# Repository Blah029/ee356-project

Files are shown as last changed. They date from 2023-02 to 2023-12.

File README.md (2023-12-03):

# ee356-project
3rd year EE356: Electronic Product Design project

- Group 10
  - E/17/146: Jayawickrama JPD
  - E/17/234: Pandukabhaya VKM
  - E/17/371
- Timeline
  - Inital planning: 3rd-23rd Oct 2022
  - Project proposal: 17th-23rd Oct 2022
  - Design: 17th Oct - 13th Nov 2022
  - Simulation: 31st Oct - 13th Nov 2022
  - Prototyping: 7th-20th Nov 2022
  - Implementation: 21st Oct 2022 - 8th Jan 2022
  - Completion: 26th Dec 2022 - 15th Jan 2023
  - Product deployment: 16th-22nd Jan 2023
</br></br>
- altium_pcb  
  Altium project for the main circuit board
- arduino_main  
  Arduino code for the project
- fritzing_diagrams  
  Circuit diagrams of components done in Fritzing
- fusion_enclosure  
  3D model of the enclosure done in Fusion 360
- proteus_simulation  
  Simulation of the project done in Proteus

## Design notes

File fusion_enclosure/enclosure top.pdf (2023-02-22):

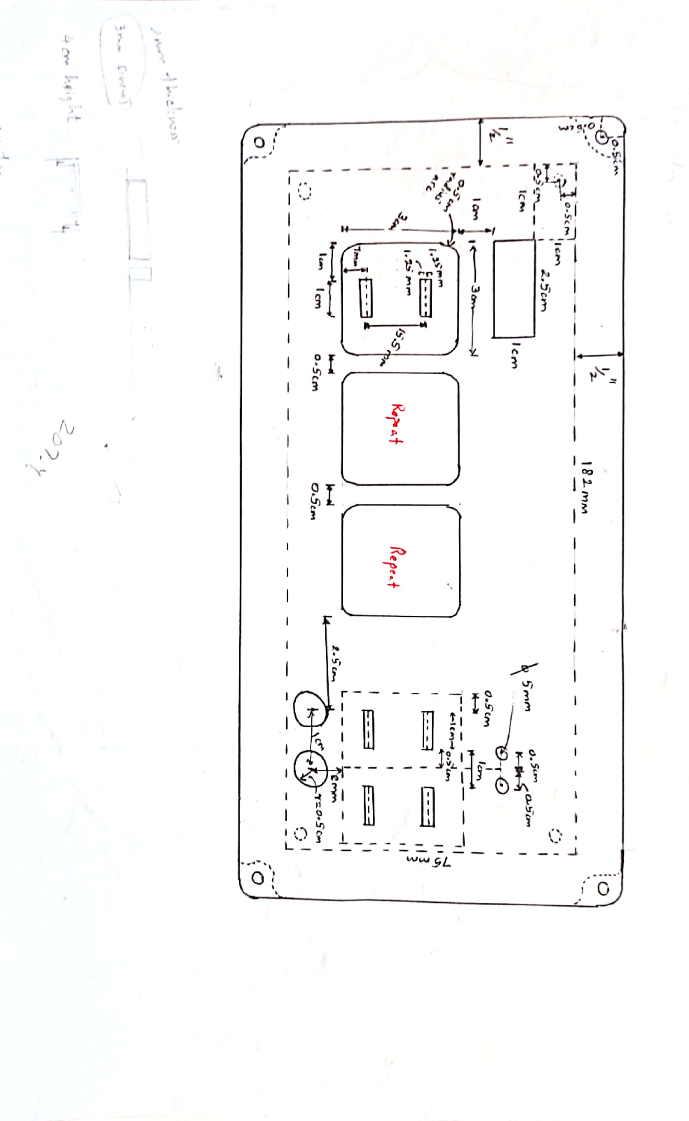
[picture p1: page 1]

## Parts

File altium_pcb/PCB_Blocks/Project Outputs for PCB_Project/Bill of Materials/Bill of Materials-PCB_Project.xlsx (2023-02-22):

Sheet: Part List Report
 | Component list |  |  | Bill of Materials for Project [PCB_Project.PrjPcb] (No PCB Document Selected)
 | Source Data From: | PCB_Project.PrjPcb |  |  | Contact: |  |  |  | Generated by:
 | Project: | PCB_Project.PrjPcb |  |  | <Parameter ClientCompanyName not found>
 | Variant: | None |  |  | <Parameter ClientContactName not found> |  |  |  | FEDEVEL
 |  |  |  |  | <Parameter ClientContactEmail not found>
 | Report Date: | 08 Feb 2023 | 1321h |  | <Parameter ClientWebsite not found> |  |  |  | http://www.fedevel.com
 | Print Date: | 2023-02-08 | 13:21:47
# | Category | Manufacturer 1 | Manufacturer Part Number 1 | Case/Package | Description | Quantity | Supplier 1 | Supplier Part Number 1 | Supplier Order Qty 1 | Supplier Stock 1 | Supplier Unit Price 1 | Supplier Subtotal 1 | Supplier Currency 1
1 | Uncategorized | Jameco Valuepro | KRS-1273B-R |  | Switch Push Button Tactile Off Momentary (On) Single Pole Single Throw Cap: 155389 155409 | 2 | Jameco | 155380 | 2000 | 2125 | 0.23 | 450.00 | USD
2 | Through-Hole Resistors | Yageo | CFR-25JB-52-220R | Axial | General Type Carbon Film Resistor 2.2kOhm 1/4W 5% Axial Bulk | 1 | Digi-Key | 220QBK-ND | 1000 | 0 | 0.01 | 11.44 | USD
3 | Through-Hole Resistors | Yageo | CFR-25JB-52-220R | Axial | General Type Carbon Film Resistor 3.3kOhm 1/4W 5% Axial Bulk, General Type Carbon Film Resistor 1kOhm 1/4W 5% Axial Bulk | 2 | Digi-Key | 220QBK-ND | 2000 | 0 | 0.01 | 22.88 | USD
4 | Through-Hole Resistors | Yageo | CFR-25JB-52-220R | Axial | General Type Carbon Film Resistor 220Ohm 1/4W 5% Axial Bulk | 16 | Digi-Key | 220QBK-ND | 16000 | 0 | 0.01 | 141.44 | USD
5 | Resistor Arrays | Bourns | 4309R-101-102LF | SIP | Res Thick Film NET 1K Ohm 2% 1.13W ±100ppm/°C BUS Molded 9-Pin SIP Pin Thru-Hole | 4 | Avnet | 32K9075 | 4000 | 21 | 1.42 | 5680.00 | USD
6 | LinearRegulator | ON Semiconductor / Fairchild | LM7805CT |  | Positive Voltage Regulator, 5 V, 1 A, -40 to 125 degC, 3-Pin TO-220, RoHS, Tube | 1 | Farnell | 1102157 | 1000 | 0 | 0.39 | 391.87 | USD
7 | LED Displays | Lumex | LDS-A5642RI | DIP | Single Digit Seven Segment Green 0.56" Common Anode Through Hole LED Display | 2 | Future Electronics | 8628562 | 2000 | 0 | 0.81 | 1610.00 | USD
8 | Diode | Lumex | SSA-LXB10HW-GF/LP |  | LED ARRAY 10X25MM 10SEG RED DIFF | 1 | Farnell | 1020492 | 1000 | 130 | 1.01 | 1008.17 | USD
9 | Diode | Broadcom Avago | HLMP-4700 |  | LED RED DIFFUSED T-1 3/4 T/H | 2 | Farnell | 1003232 | 2000 | 67296 | 0.26 | 524.11 | USD
10 | Crystals | TXC | 9B-16.000MBBK-B | Metal | Crystal 16MHz ±50ppm (Tol) ±50ppm (Stability) 20pF FUND 30Ohm 2-Pin DIP HC-49/S Thru-Hole Bulk | 1 | Arrow Electronics | 9B-16.000MBBK-B | 1000 | 908 | 0.14 | 139.70 | USD
11 | Connectors | Sullins | PPTC021LFBN-RC |  | Female, 2C, Straight, .100"CC; 3.20mm Tail, No Mt. 100u" Tin; PBT, Phos Bronze, 105 C | 1 | Digi-Key | S7000-ND | 1000 | 123778 | 0.15 | 152.78 | USD
12 |  |  |  |  |  | 3
13 |  |  |  |  |  | 4
14 |  | Microchip | ATMEGA328P-PU |  | 8-bit AVR Microcontroller, 32KB Flash, 1KB EEPROM, 2KB SRAM, 28-pin PDIP, Industrial Grade (-40°C to 85°C) | 1 | Rs | 1310276 | 1000 | 0 | 2.75 | 2753.98 | USD
15 |  | Texas Instruments | SN74HC595N |  | 8-Bit Shift Registers With 3-State Output Registers, N0016A, TUBE | 1 | Rs | 1000763 | 1000 | 3750 | 0.46 | 456.17 | USD
16 |  | Texas Instruments | SN74LS47N |  | BCD-to-7-Segment Decoder / Driver, 4.75 to 5.25 V, 0 to 70 degC, 16-pin DIP (N16), Pb-Free (RoHS) | 2 | Digi-Key | 296-3712-5-ND | 2000 | 5948 | 0.82 | 1641.52 | USD
17 |  | Murata | RCER71E106K3A2H03B | Radial | Cap Ceramic 10uF 25V X7R ±10% Radial 2.5mm +125°C Automotive Bulk | 2 | Future Electronics | 2087210 | 2000 | 0 | 0.36 | 720.00 | USD
18 |  | KEMET | C315C220K1G5TA |  | Capacitor, Ceramic, 22 pF, +/-10 %, 100 V, -55 to 125 degC, 2-Pin THD, RoHS, Bulk | 3 | Farnell | 2938971 | 3000 | 0 | 0.14 | 425.84 | USD
19 |  | TI National Semiconductor | LM3914N-1 | DIP | IC DRVR DOT/BAR DISPLAY 18DIP | 1 |  |  |  | 0
20 |  | Texas Instruments | SN74LS165AN |  | Serial-out shift registers, N0016A, TUBE | 3 | Newark | 28AH5081 | 3000 | 0 | 0.69 | 2058.00 | USD
 |  |  |  |  |  | 53 |  |  | 45000 |  |  | 18187.9
Approved |  |  |  | Notes
 |  |  |  |  |  | 1000 | pcs: | Total |  | 18187.9 |  | USD
 |  |  |  |  |  |  |  | Price for 1pcs |  | 18.19 |  | USD

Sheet: Project Information
Project Full Path | D:\continuum\eng\elec\y3s2\ee356\projects\ee356-project\ee356-project\altium_pcb\PCB_Project\PCB_Project.PrjPcb
Project Filename | PCB_Project.PrjPcb
Variant Name | None
Data-Source Filename | PCB_Project.PrjPcb
Data-Source Full Path | D:\continuum\eng\elec\y3s2\ee356\projects\ee356-project\ee356-project\altium_pcb\PCB_Project\PCB_Project.PrjPcb
Title | Bill of Materials for Project [PCB_Project.PrjPcb] (No PCB Document Selected)
Total Quantity | 53
Report Time | 1321h
Report Date | 08 Feb 2023
Report Date & Tine | 08 Feb 2023 1321h
Output Name | Bill of Materials
Output Type | BomReport
Output Generator Name | BOM
Output Generator Description | Bill of Materials

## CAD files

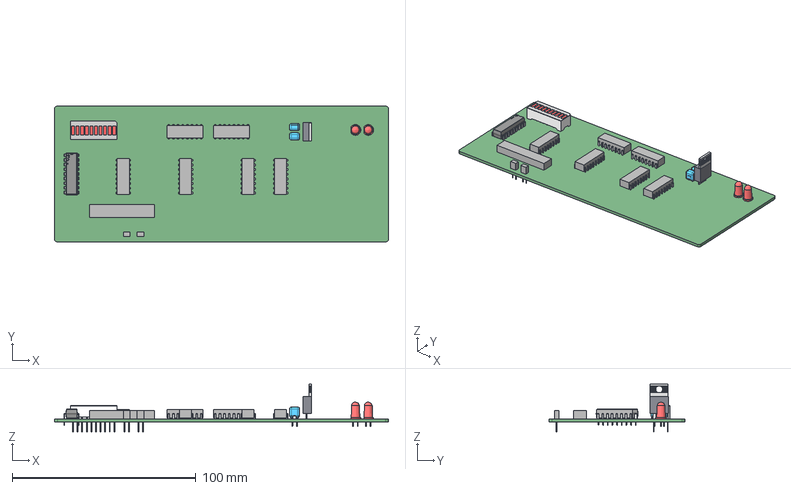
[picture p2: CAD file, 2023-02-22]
altium_pcb/PCB_Blocks/Project Outputs for Free Documents/Export STEP/PCB1.step
182.0 x 74.0 x 25.9 mm
Extruded x 342
Logo x 2
Leads x 2
MainBody x 2
Texas Logo Yury - Copy
Texas Logo Yury
top
led
pins x 3
led base x 2
led head x 2

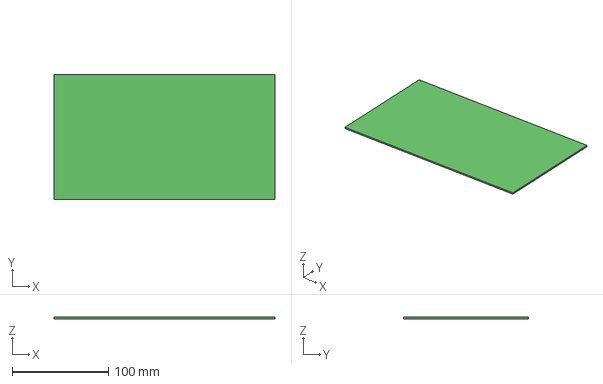
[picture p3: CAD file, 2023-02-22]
altium_pcb/PCB_Blocks/Project Outputs for PCB_Blocks/Export STEP/PCB_Blocks.step
230.0 x 130.0 x 1.69 mm

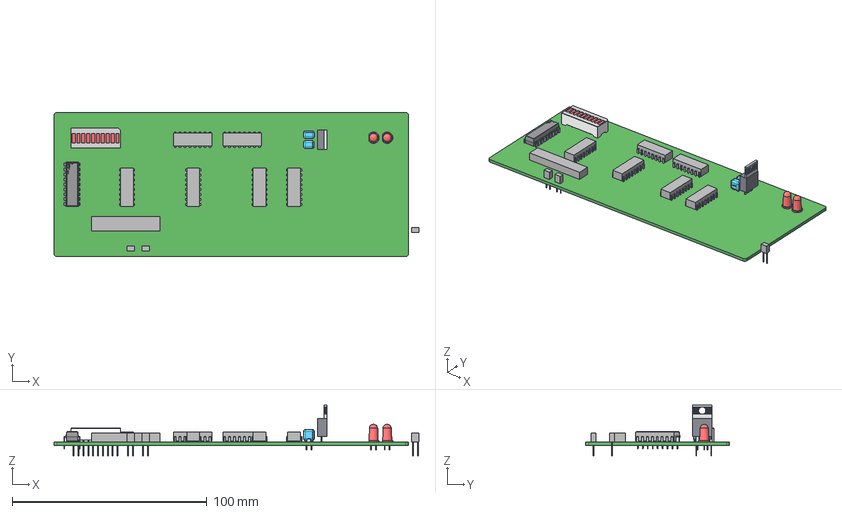
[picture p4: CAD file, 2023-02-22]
altium_pcb/PCB_Blocks/Project Outputs for PCB_Project/Export STEP/PCB1.step
187.3 x 74.0 x 25.9 mm
Extruded x 345
Logo x 2
Leads x 2
MainBody x 2
Texas Logo Yury - Copy
Texas Logo Yury
top
led
pins x 3
led base x 2
led head x 2

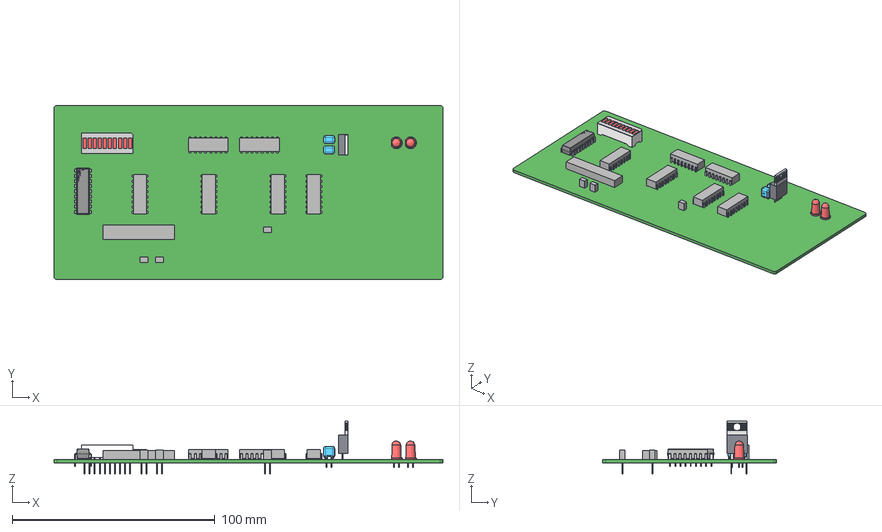
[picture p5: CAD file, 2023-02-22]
altium_pcb/PCB_Project/Project Outputs for PCB_Project/Export STEP/PCB1.step
192.0 x 86.0 x 25.9 mm
Extruded x 345
Logo x 2
Leads x 2
MainBody x 2
Texas Logo Yury - Copy
Texas Logo Yury
top
led
pins x 3
led base x 2
led head x 2

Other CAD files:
fusion_enclosure/Top of the Enclosure v13.dwg
fusion_enclosure/Top of the Enclosure v13.f3z

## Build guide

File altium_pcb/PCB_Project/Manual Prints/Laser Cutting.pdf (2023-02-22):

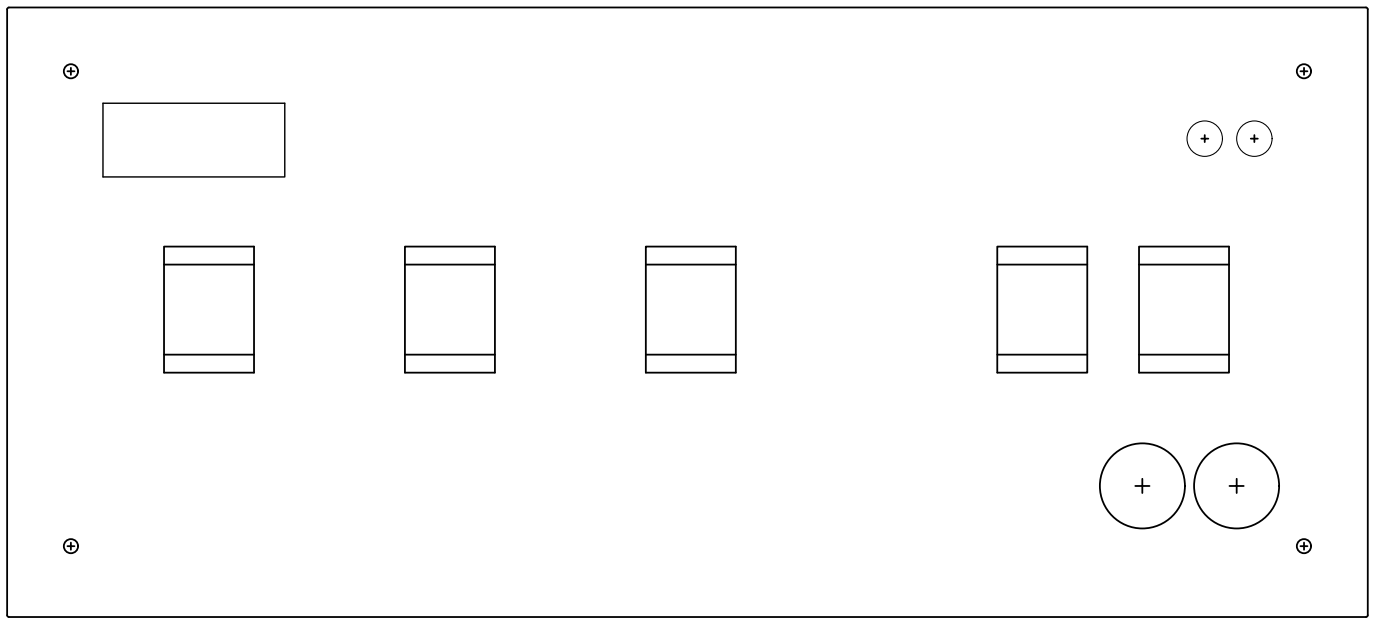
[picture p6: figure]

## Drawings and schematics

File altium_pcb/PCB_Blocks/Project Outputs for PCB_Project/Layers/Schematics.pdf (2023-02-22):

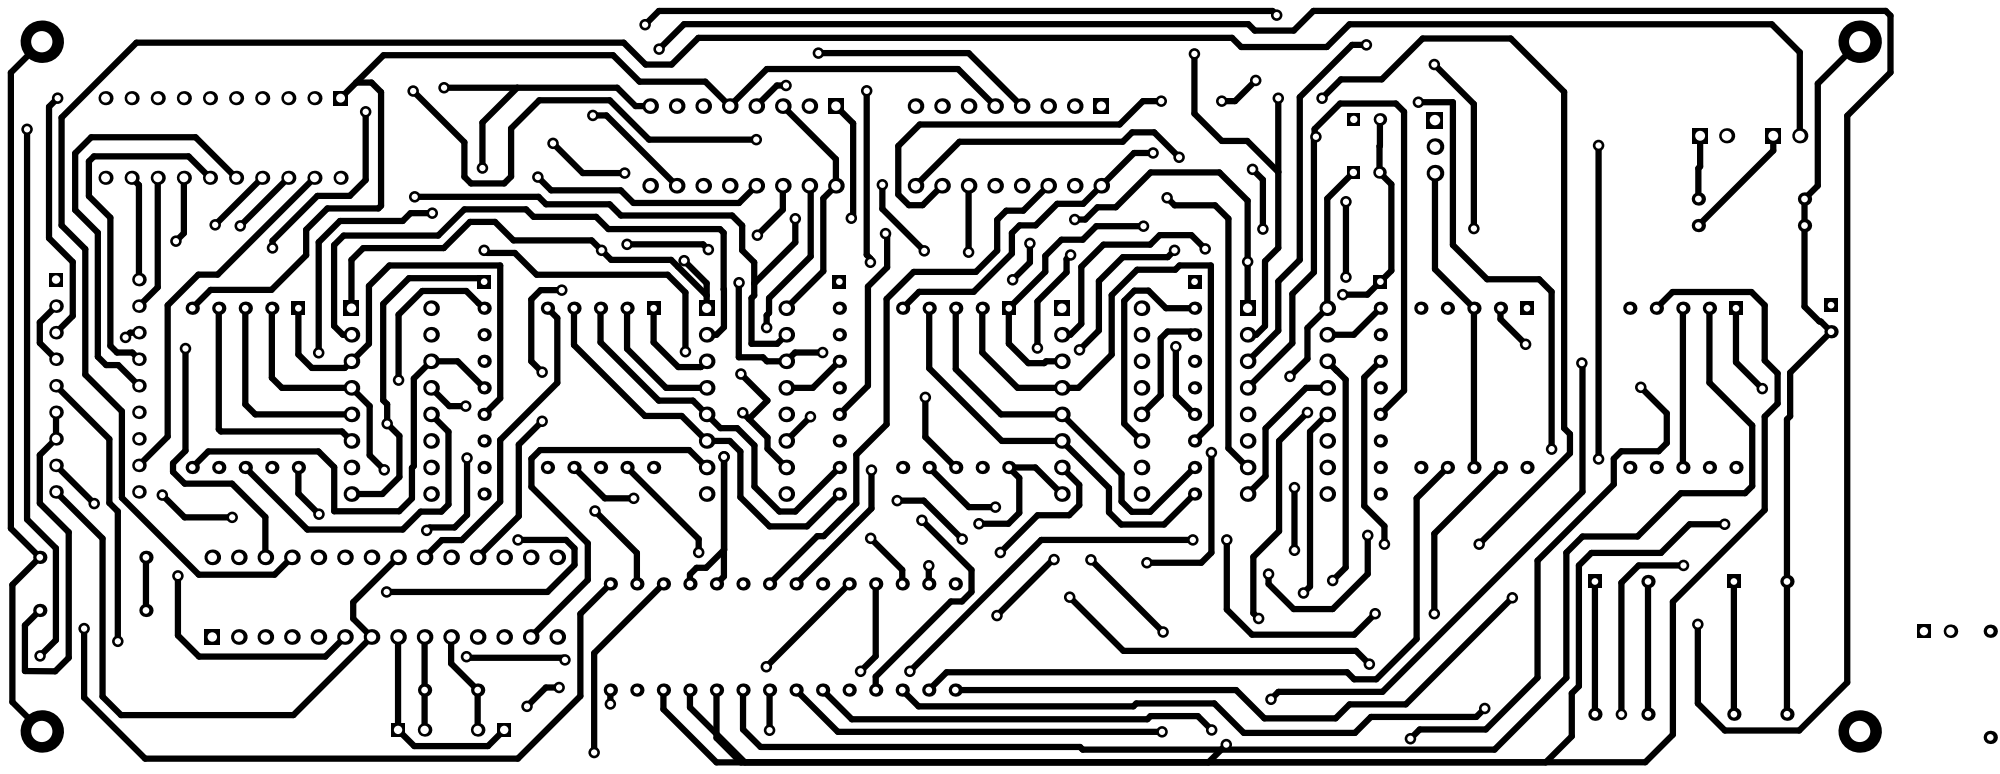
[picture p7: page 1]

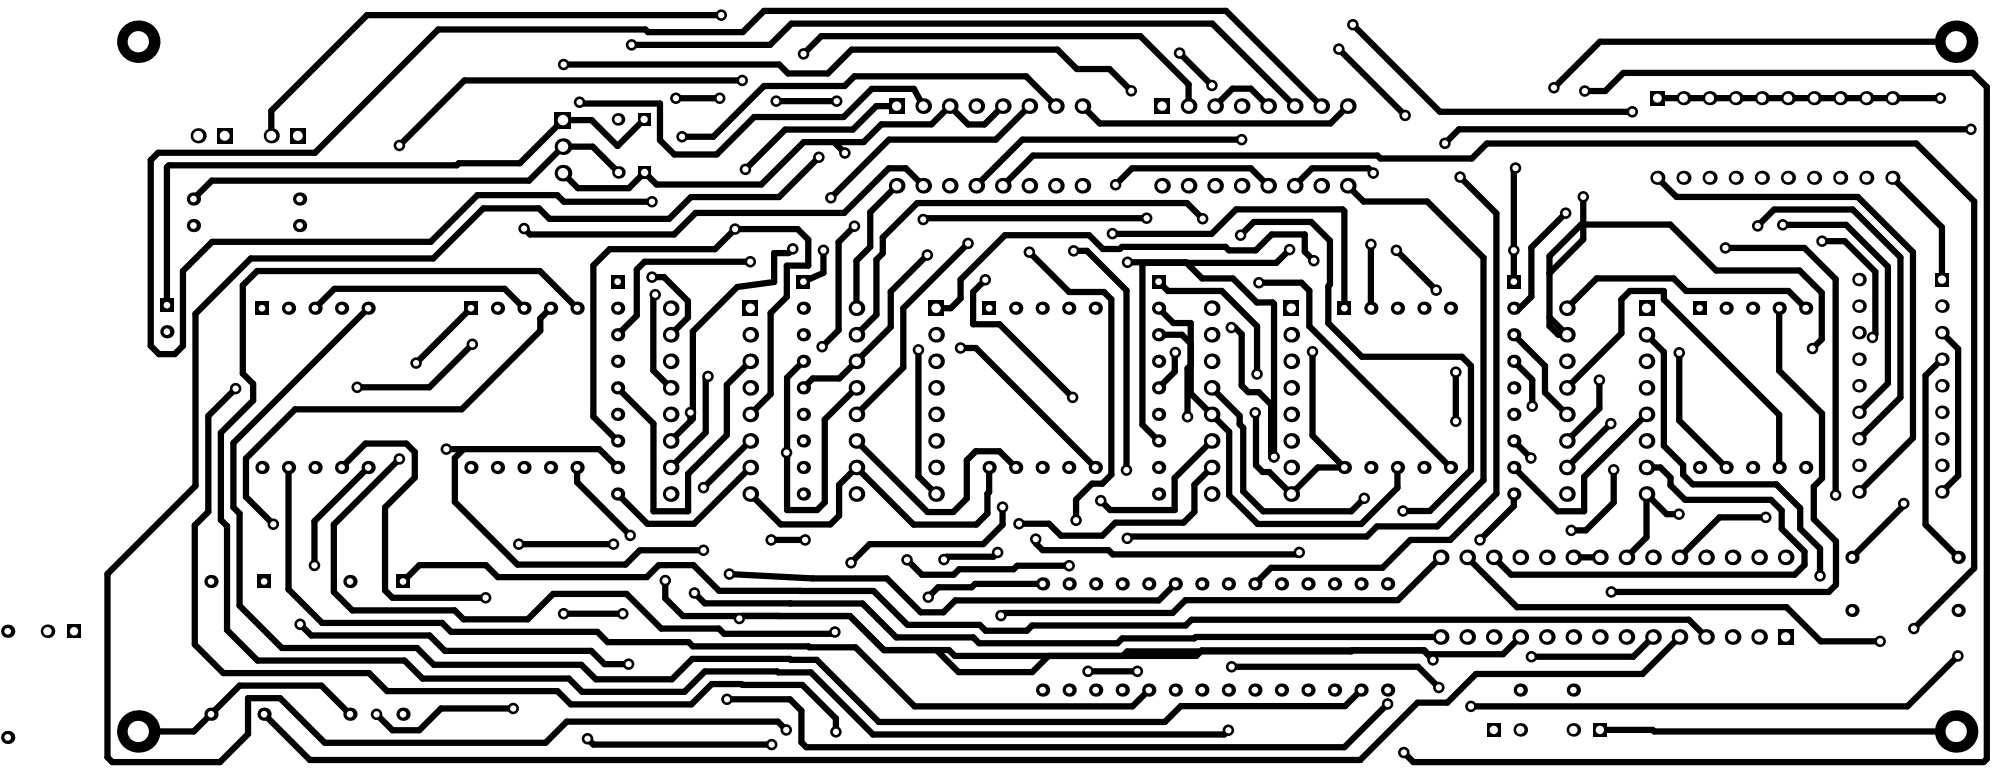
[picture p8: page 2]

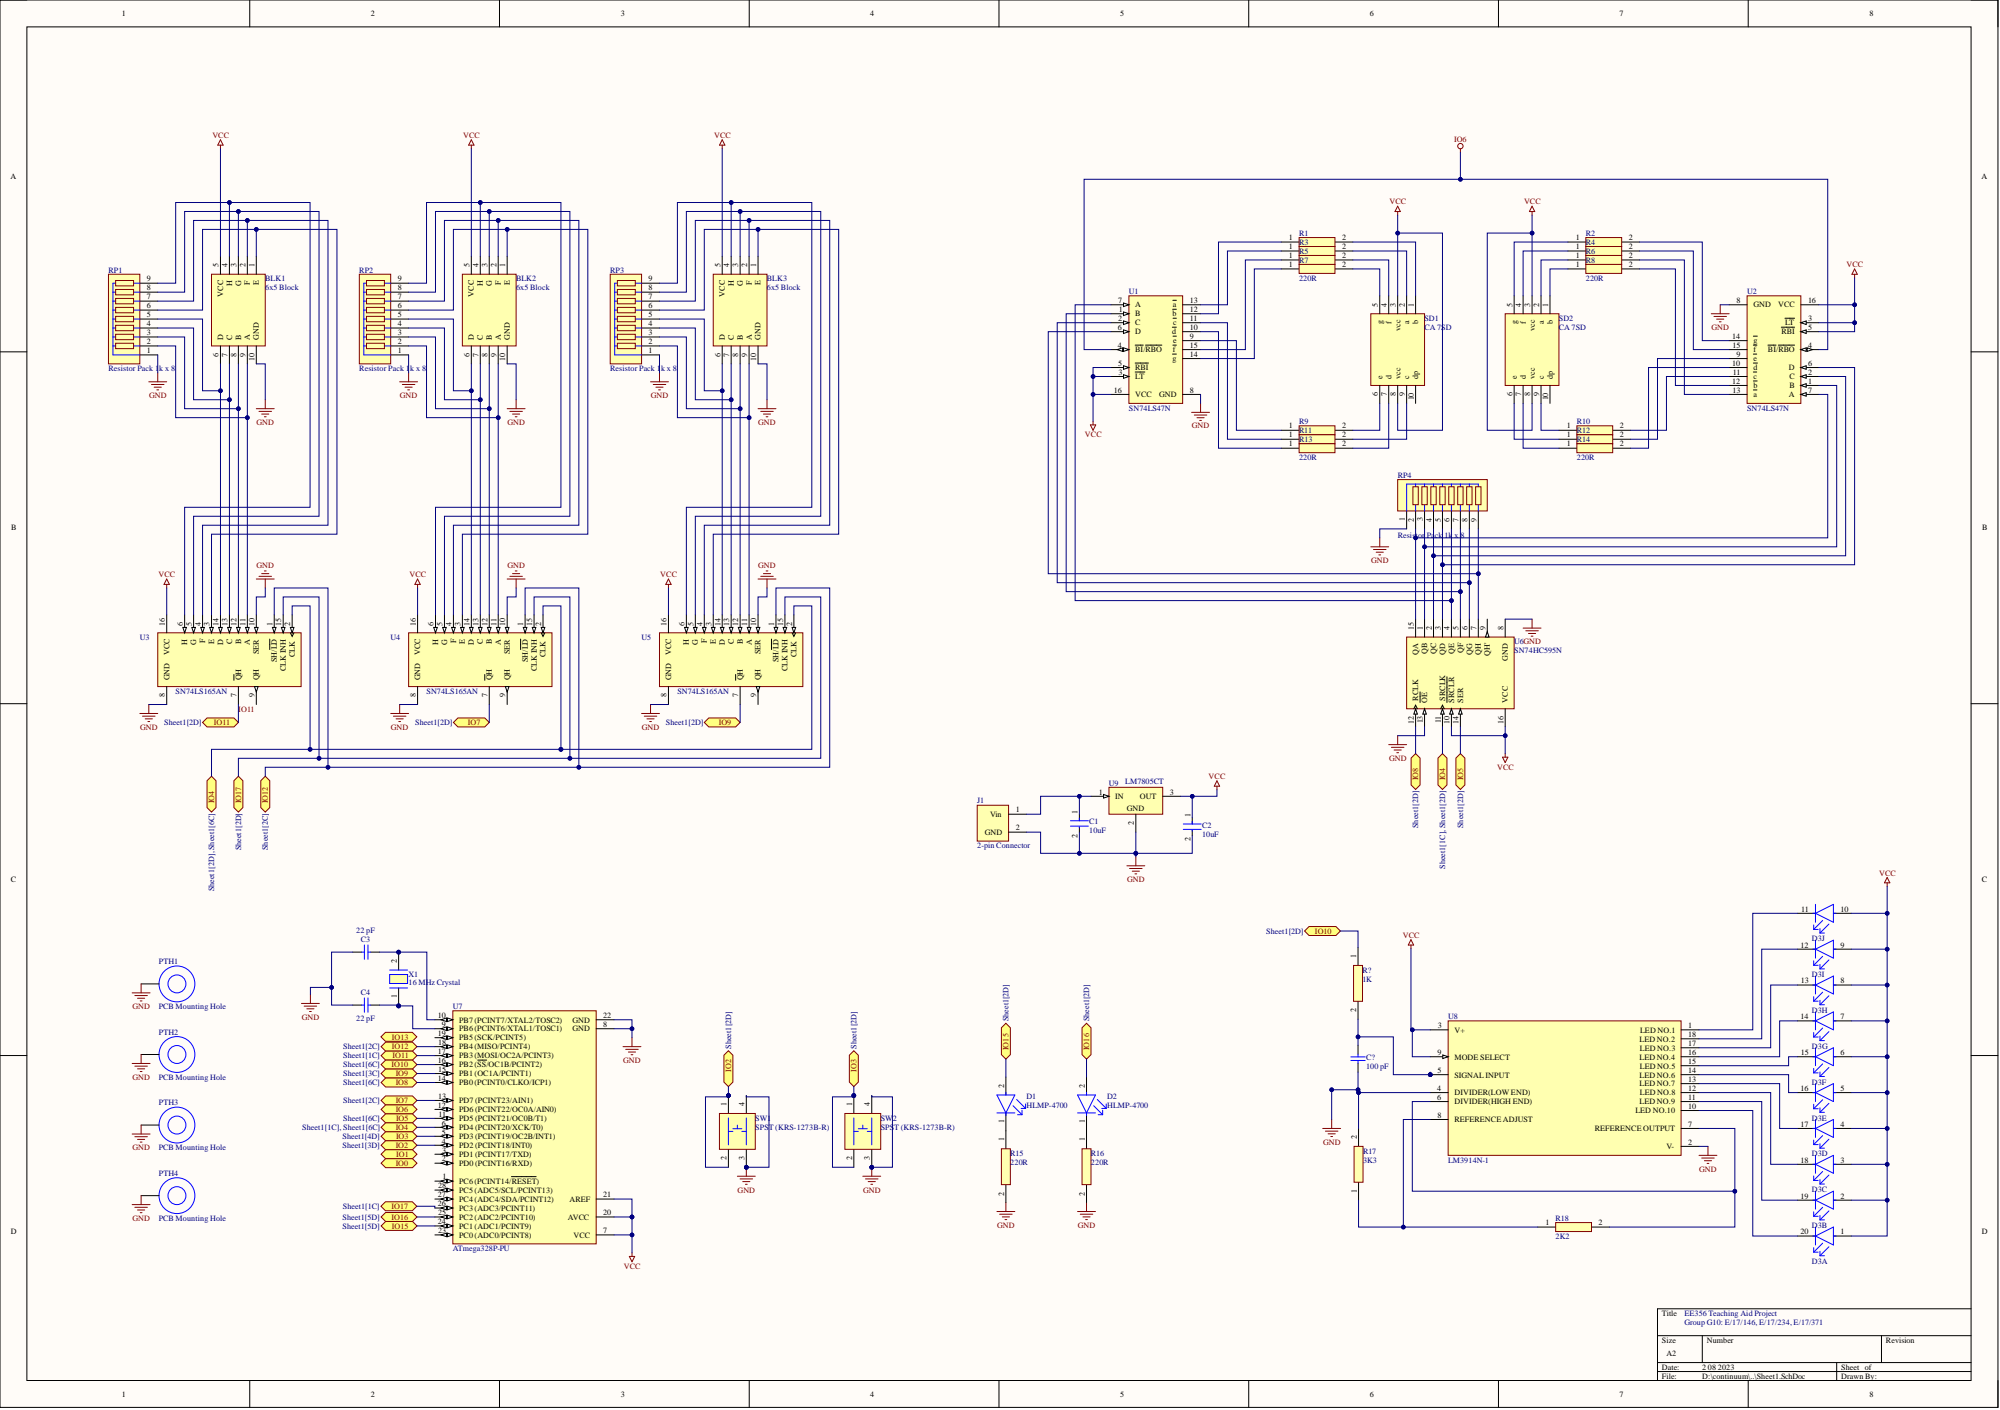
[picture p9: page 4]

GND PCB Mounting Hole

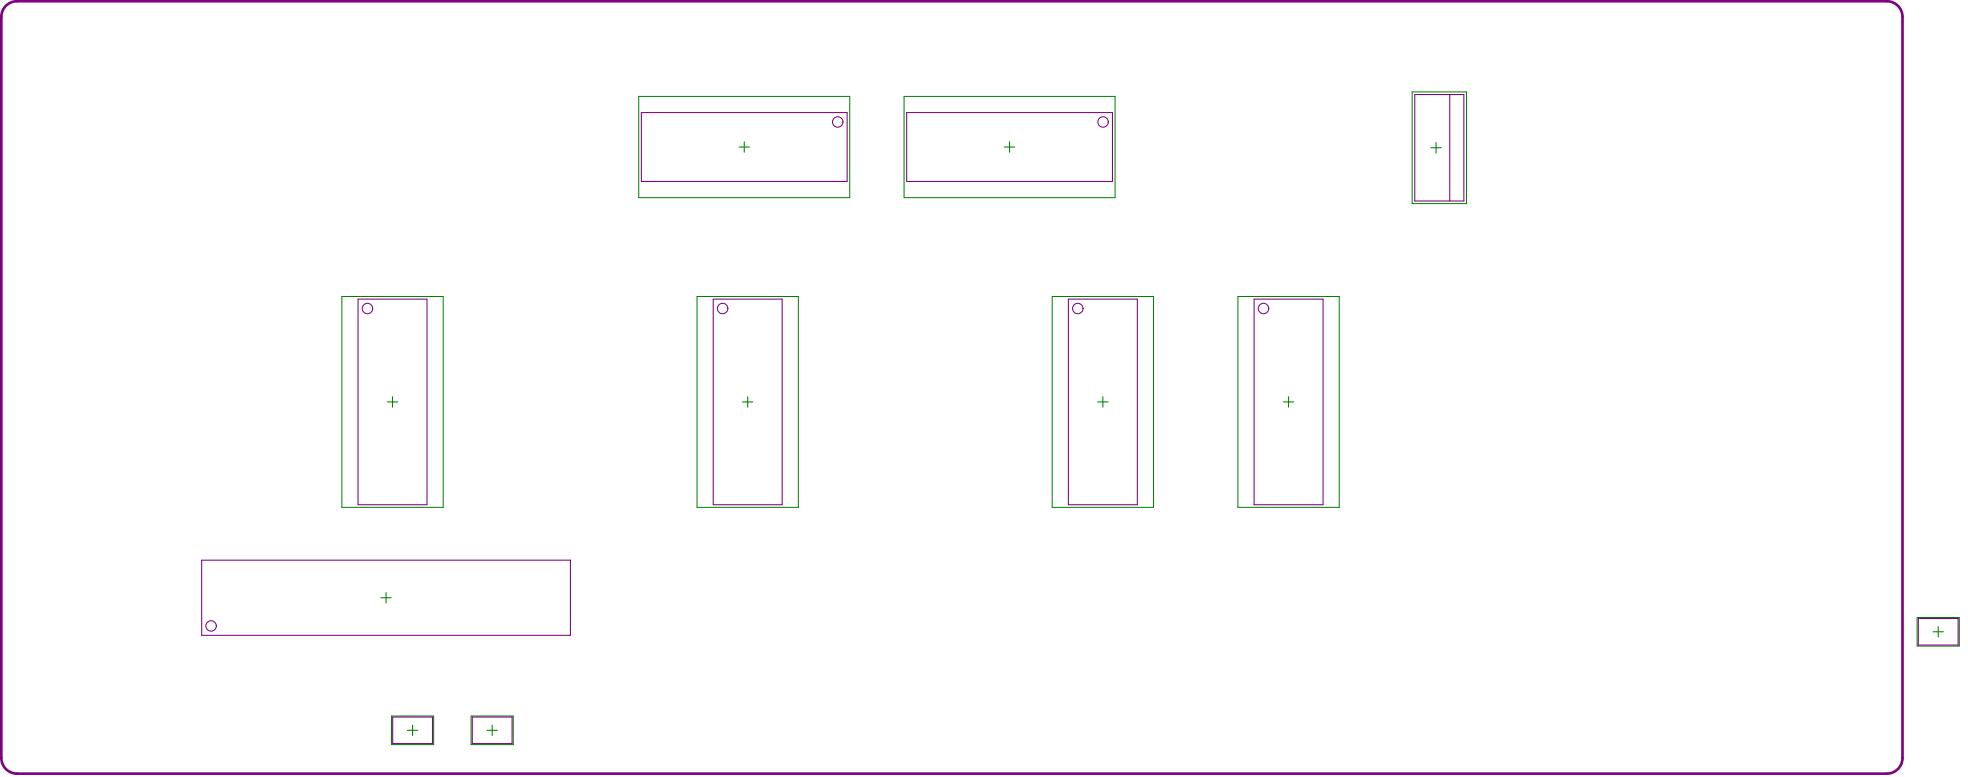
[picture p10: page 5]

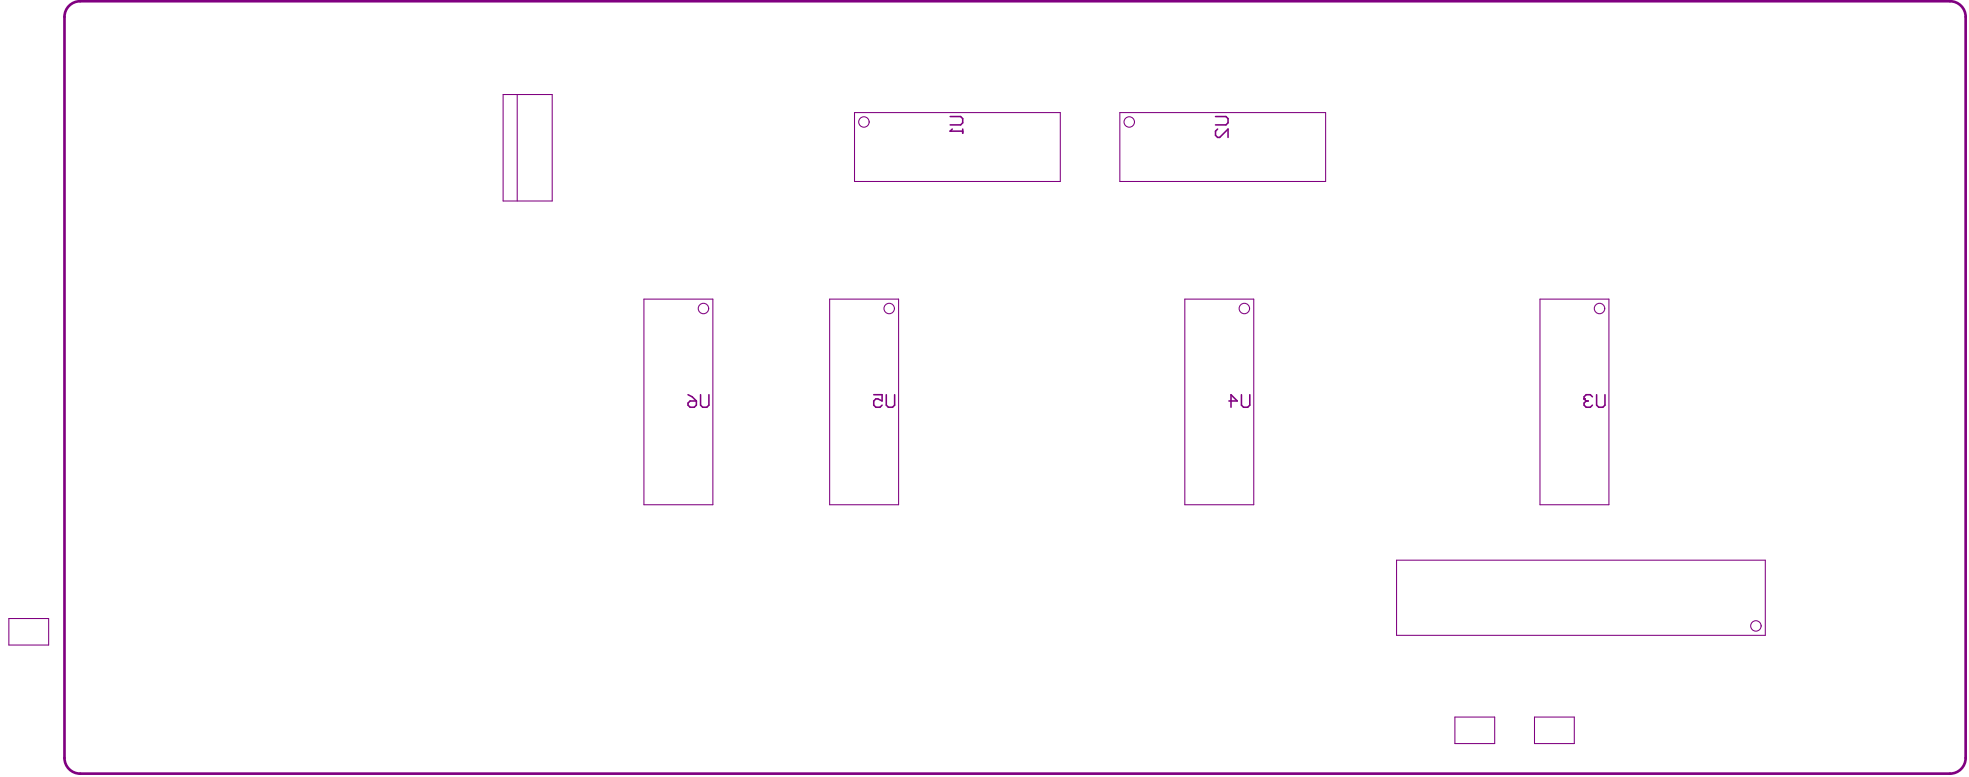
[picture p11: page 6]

Component | list | | Bill of Materials for Project [PCB_Project.PrjPcb] (No PCB Document Selected)
Source Data From: PCB_Project.PrjPcb | | Contact: | | Generated by:
Project: PCB_Project.PrjPcb | <Parameter ClientCompanyName not found>
Variant: | None | <Parameter ClientContactName not found> | FEDEVEL <Parameter ClientContactEmail not found>
Report Date: | 08 Feb 2023 | 1319h | <Parameter ClientWebsite not found> | http://www.fedevel.com

### Print Date: 08-Feb-23 1:20:32 PM

# | Category | Manufacturer 1 | Manufacturer Part Number 1 | Case/Package | Description | Quantity | Supplier 1 | Supplier Part Number 1 | Supplier Order Qty 1 | Supplier Stock 1 | Supplier Unit Price 1 | Supplier Subtotal 1 | Supplier Currency 1

1 | Uncategorized | Jameco Valuepro | KRS-1273B-R | | Sw itch Push Button Tactile Off Momentary | 2 | Jameco | 155380 | 2000 | 2125 | 0.23 | 450.00 | USD
2 | Through-Hole Resistors | Yageo | CFR-25JB-52-220R | Axial | General Type Carbon Film Resistor 2.2kOhm | 1 | Digi-Key | 220QBK-ND | 1000 | 0 | 0.01 | 11.44 | USD
3 | Through-Hole Resistors | Yageo | CFR-25JB-52-220R | Axial | General Type Carbon Film Resistor 3.3kOhm | 2 | Digi-Key | 220QBK-ND | 2000 | 0 | 0.01 | 22.88 | USD
4 | Through-Hole Resistors | Yageo | CFR-25JB-52-220R | Axial | General Type Carbon Film Resistor 220Ohm | 16 | Digi-Key | 220QBK-ND | 16000 | 0 | 0.01 | 141.44 | USD
5 | Resistor Arrays | Bourns | 4309R-101-102LF | SIP | Res Thick Film NET 1K Ohm 2% 1.13W | 4 | Avnet | 32K9075 | 4000 | 21 | 1.42 | 5680.00 | USD
6 | LinearRegulator | ON Semiconductor / Fairchild | LM7805CT | | Positive Voltage Regulator, 5 V, 1 A, -40 to | 1 | Farnell | 1102157 | 1000 | 0 | 0.39 | 391.87 | USD
7 | LED Displays | Lumex | LDS-A5642RI | DIP | Single Digit Seven Segment Green 0.56" | 2 | Future Electronics | 8628562 | 2000 | 0 | 0.81 | 1610.00 | USD
8 | Diode | Lumex | SSA-LXB10HW-GF/LP | | LED ARRAY 10X25MM 10SEG RED DIFF | 1 | Farnell | 1020492 | 1000 | 130 | 1.01 | 1008.17 | USD
9 | Diode | Broadcom Avago | HLMP-4700 | | LED RED DIFFUSED T-1 3/4 T/H | 2 | Farnell | 1003232 | 2000 | 67296 | 0.26 | 524.11 | USD
10 | Crystals | TXC | 9B-16.000MBBK-B | Metal | Crystal 16MHz ±50ppm (Tol) ±50ppm | 1 | Arrow Electronics | 9B-16.000MBBK-B | 1000 | 908 | 0.14 | 139.70 | USD
11 | Connectors | Sullins | PPTC021LFBN-RC | | Female, 2C, Straight, .100"CC; 3.20mm Tail, | 1 | Digi-Key | S7000-ND | 1000 | 123778 | 0.15 | 152.78 | USD
12 | | | | | | 3
13 | | | | | | 4
14 | | Microchip | ATMEGA328P-PU | | 8-bit AVR Microcontroller, 32KB Flash, 1KB | 1 | Rs | 1310276 | 1000 | 0 | 2.75 | 2753.98 | USD
15 | | Texas Instruments | SN74HC595N | | 8-Bit Shift Registers With 3-State Output | 1 | Rs | 1000763 | 1000 | 3750 | 0.46 | 456.17 | USD
16 | | Texas Instruments | SN74LS47N | | BCD-to-7-Segment Decoder / Driver, 4.75 to | 2 | Digi-Key | 296-3712-5-ND | 2000 | 5948 | 0.82 | 1641.52 | USD
17 | | Murata | RCER71E106K3A2H03B | Radial | Cap Ceramic 10uF 25V X7R ±10% Radial | 2 | Future Electronics | 2087210 | 2000 | 0 | 0.36 | 720.00 | USD
18 | | KEMET | C315C220K1G5TA | | Capacitor, Ceramic, 22 pF, +/-10 %, 100 V, - | 3 | Farnell | 2938971 | 3000 | 0 | 0.14 | 425.84 | USD
19 | | TI National Semiconductor | LM3914N-1 | DIP | IC DRVR DOT/BAR DISPLAY 18DIP | 1 | | | | 0
20 | | Texas Instruments | SN74LS165AN | | Serial-out shift registers, N0016A, TUBE | 3 | New ark | 28AH5081 | 3000 | 0 | 0.69 | 2058.00 | USD
| | | | | | 53 | | | 45000 | 18187.9
Approved | | | | Notes Price for 1pcs | | | | | | | | USD
1000 pcs: | Total | USD

18187.9

18.19

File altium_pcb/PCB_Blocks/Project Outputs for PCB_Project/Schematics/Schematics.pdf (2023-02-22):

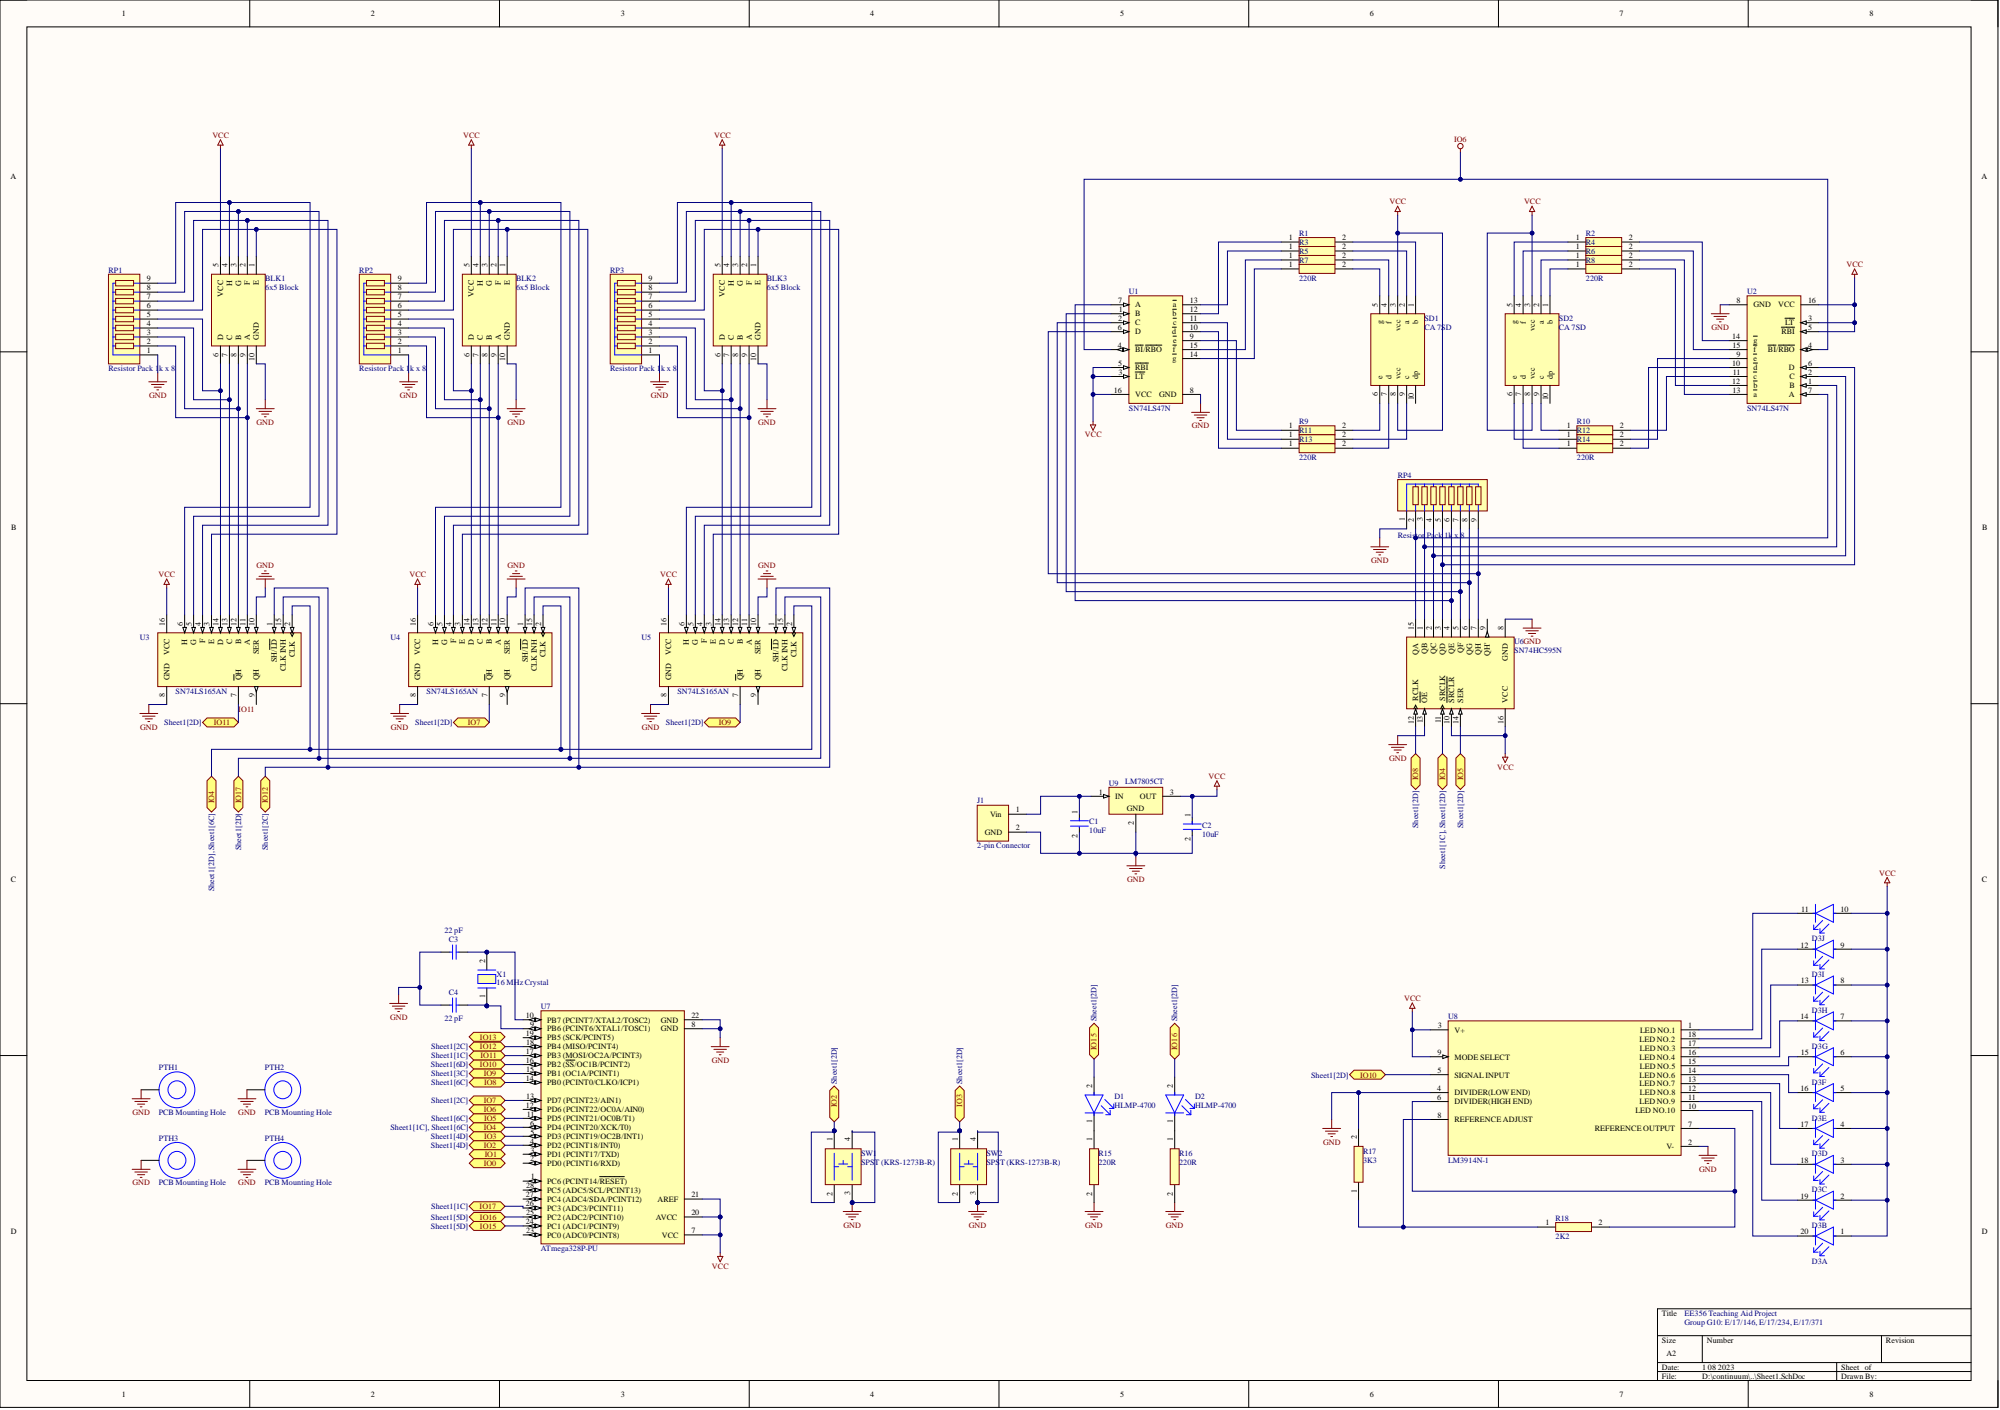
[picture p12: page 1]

GND PCB Mounting Hole

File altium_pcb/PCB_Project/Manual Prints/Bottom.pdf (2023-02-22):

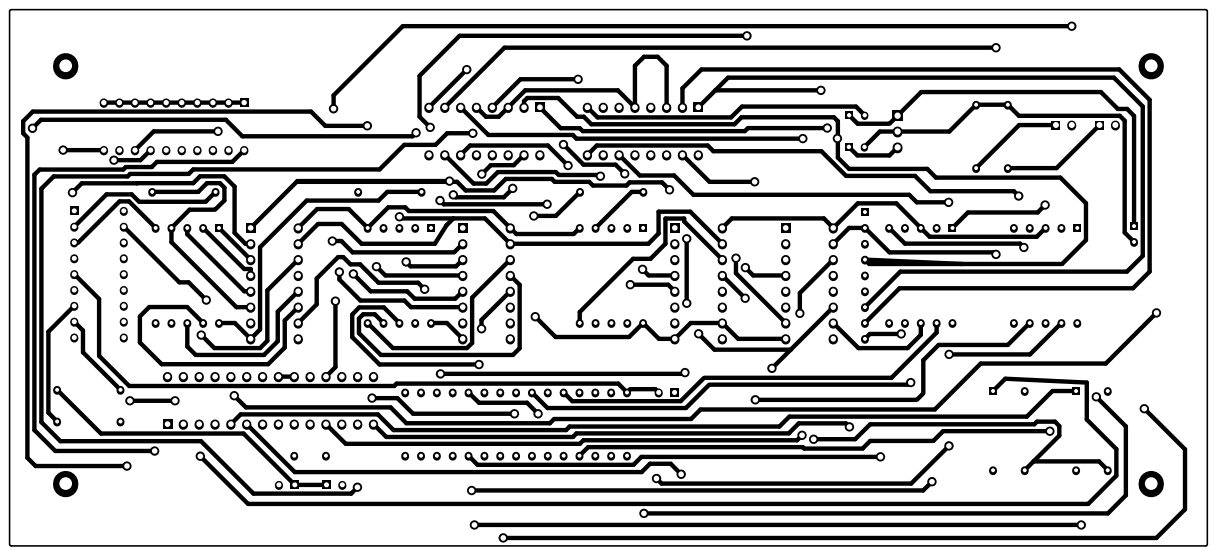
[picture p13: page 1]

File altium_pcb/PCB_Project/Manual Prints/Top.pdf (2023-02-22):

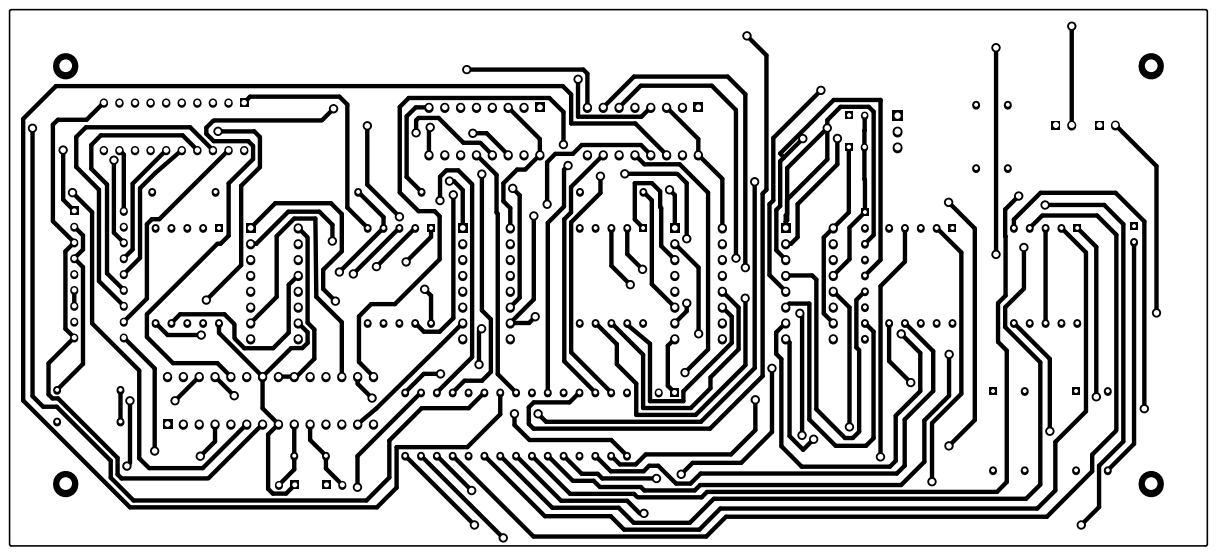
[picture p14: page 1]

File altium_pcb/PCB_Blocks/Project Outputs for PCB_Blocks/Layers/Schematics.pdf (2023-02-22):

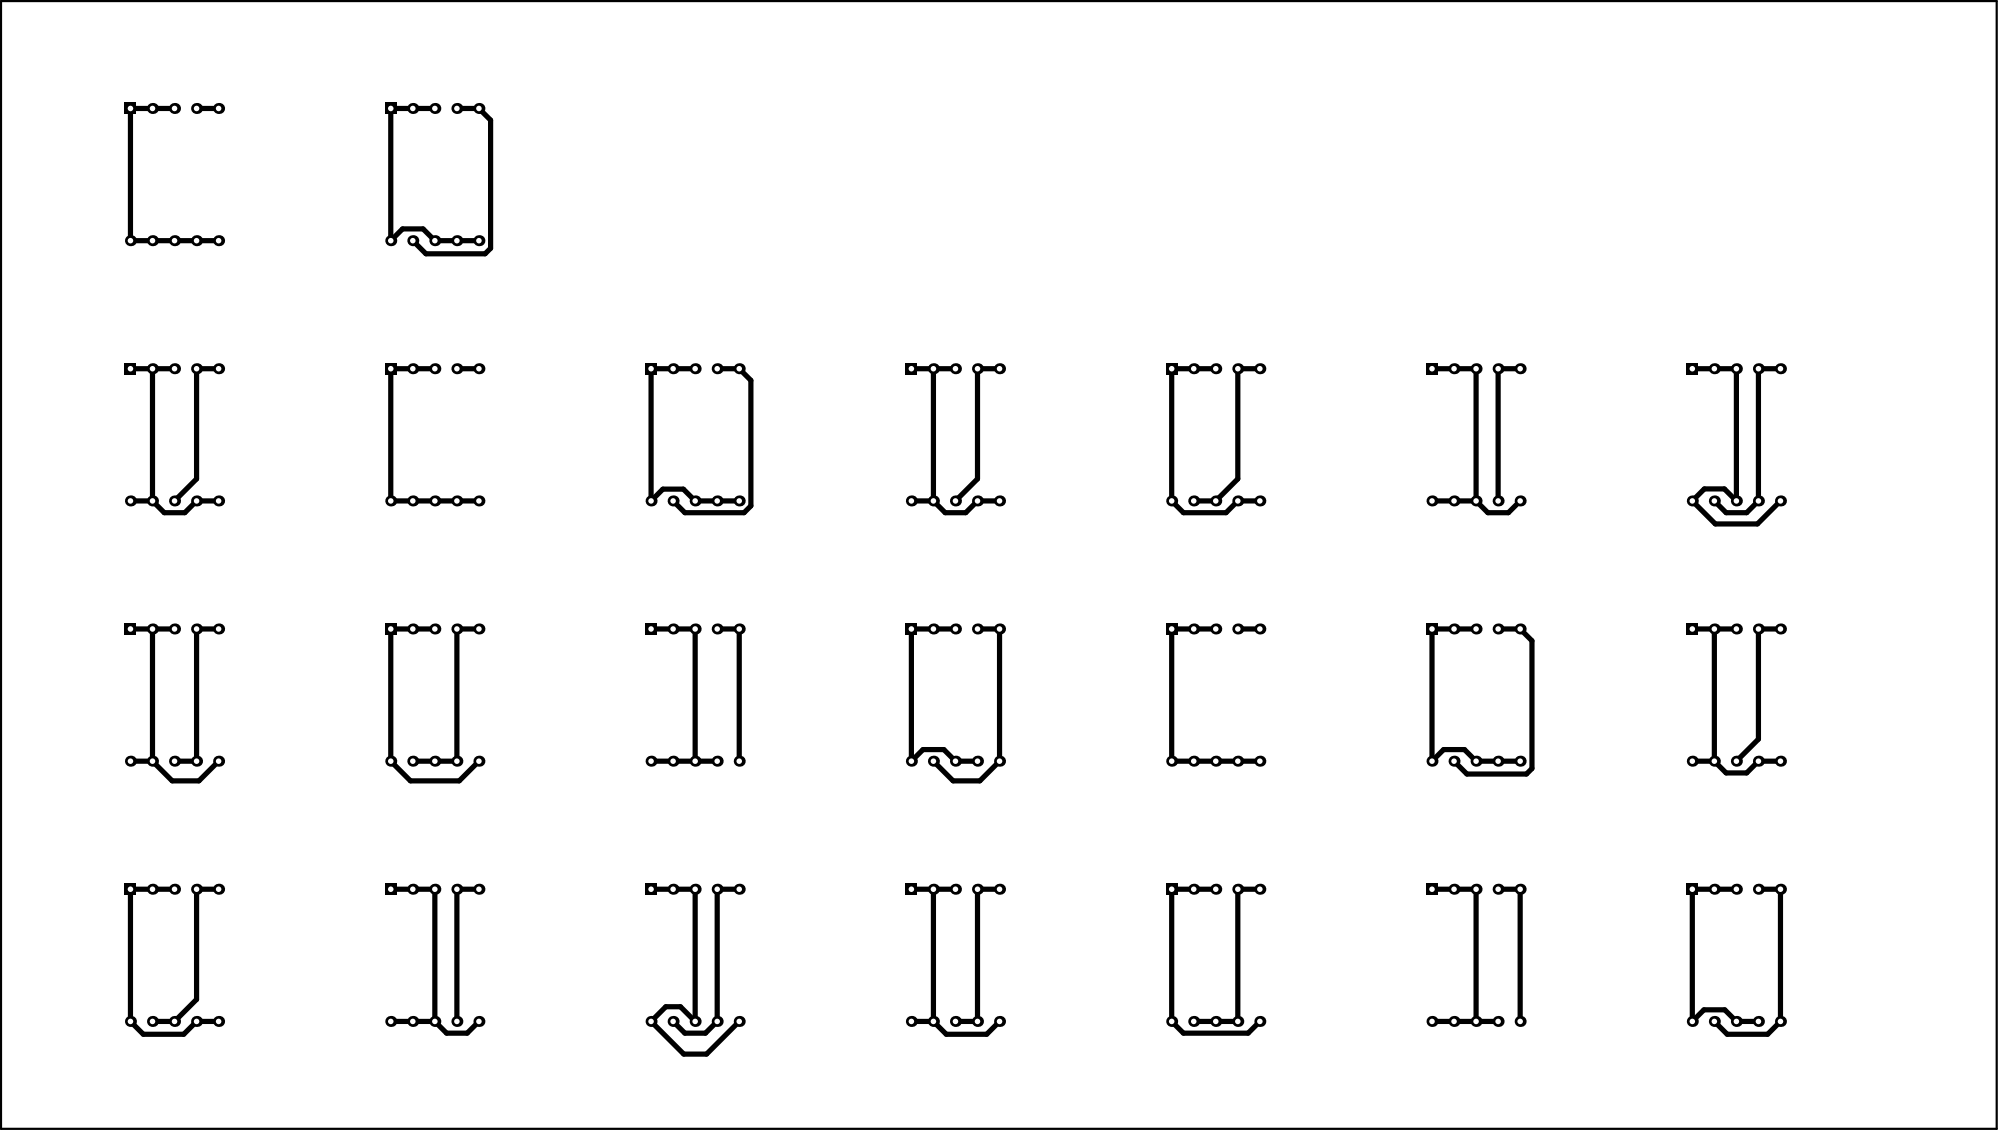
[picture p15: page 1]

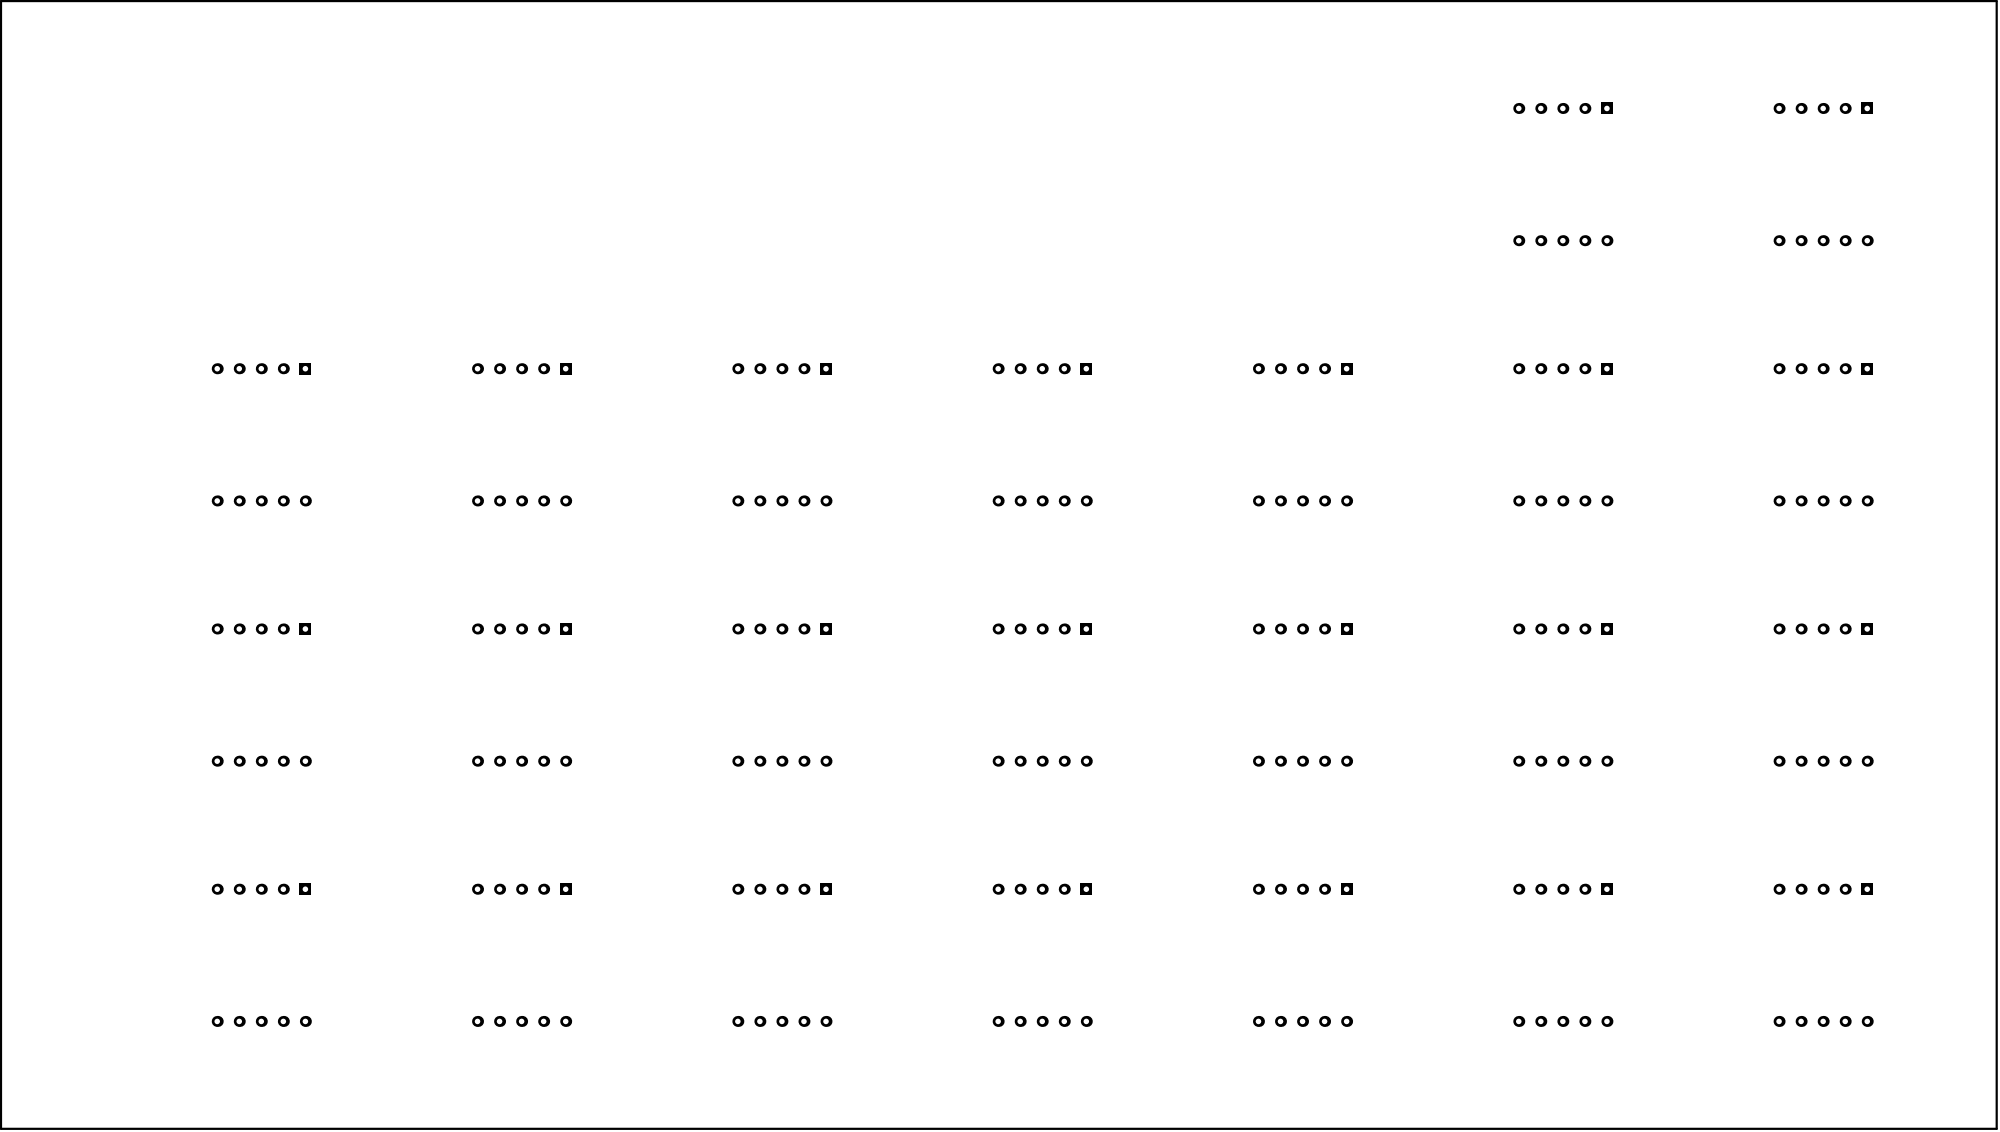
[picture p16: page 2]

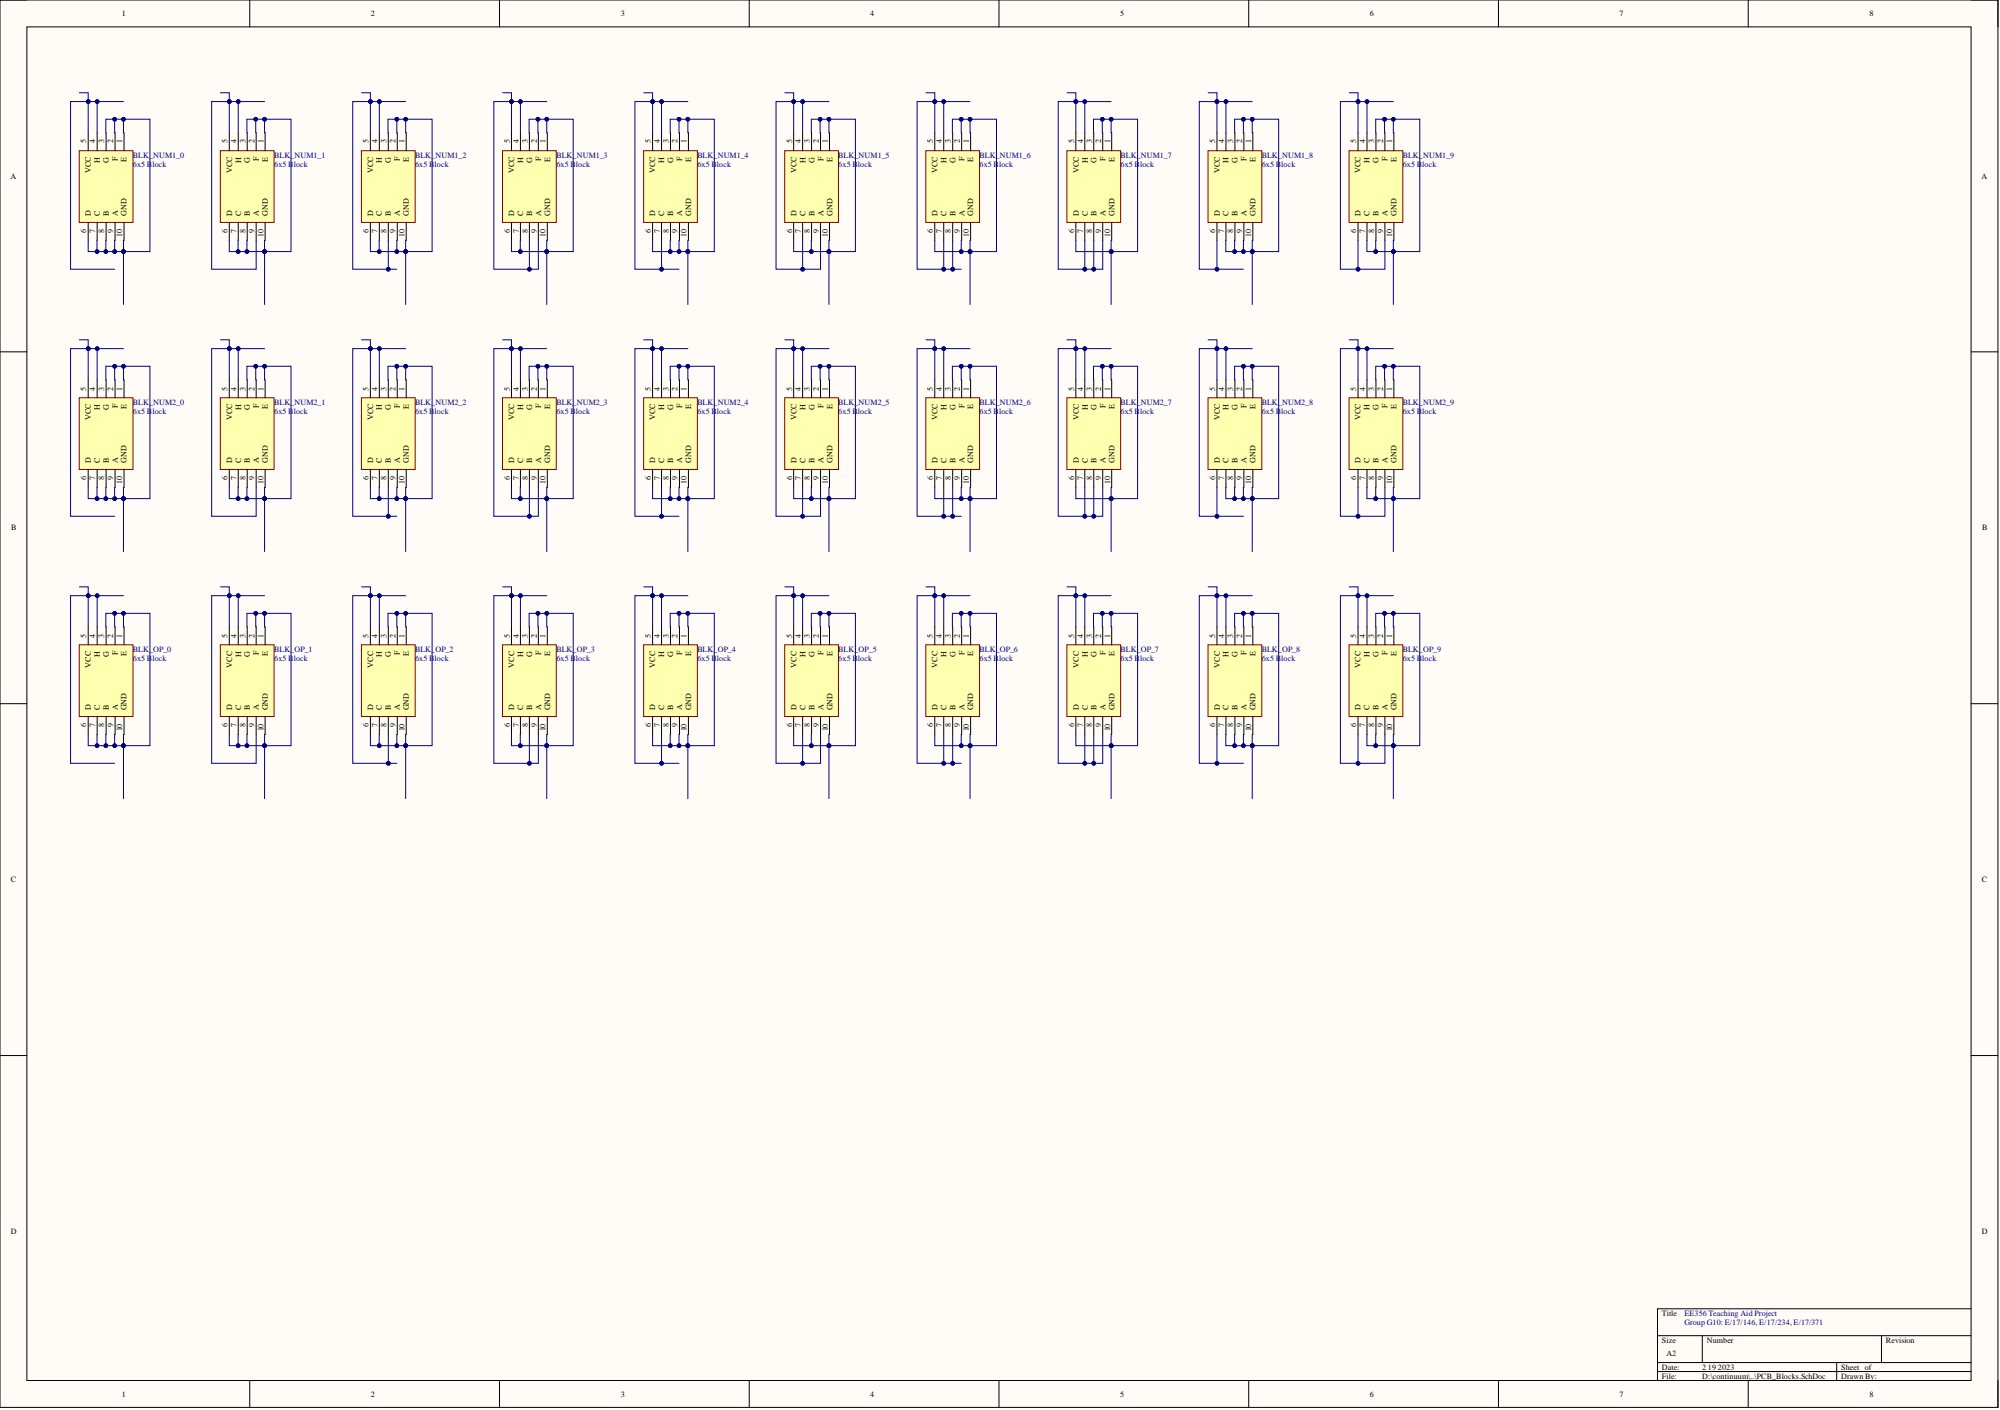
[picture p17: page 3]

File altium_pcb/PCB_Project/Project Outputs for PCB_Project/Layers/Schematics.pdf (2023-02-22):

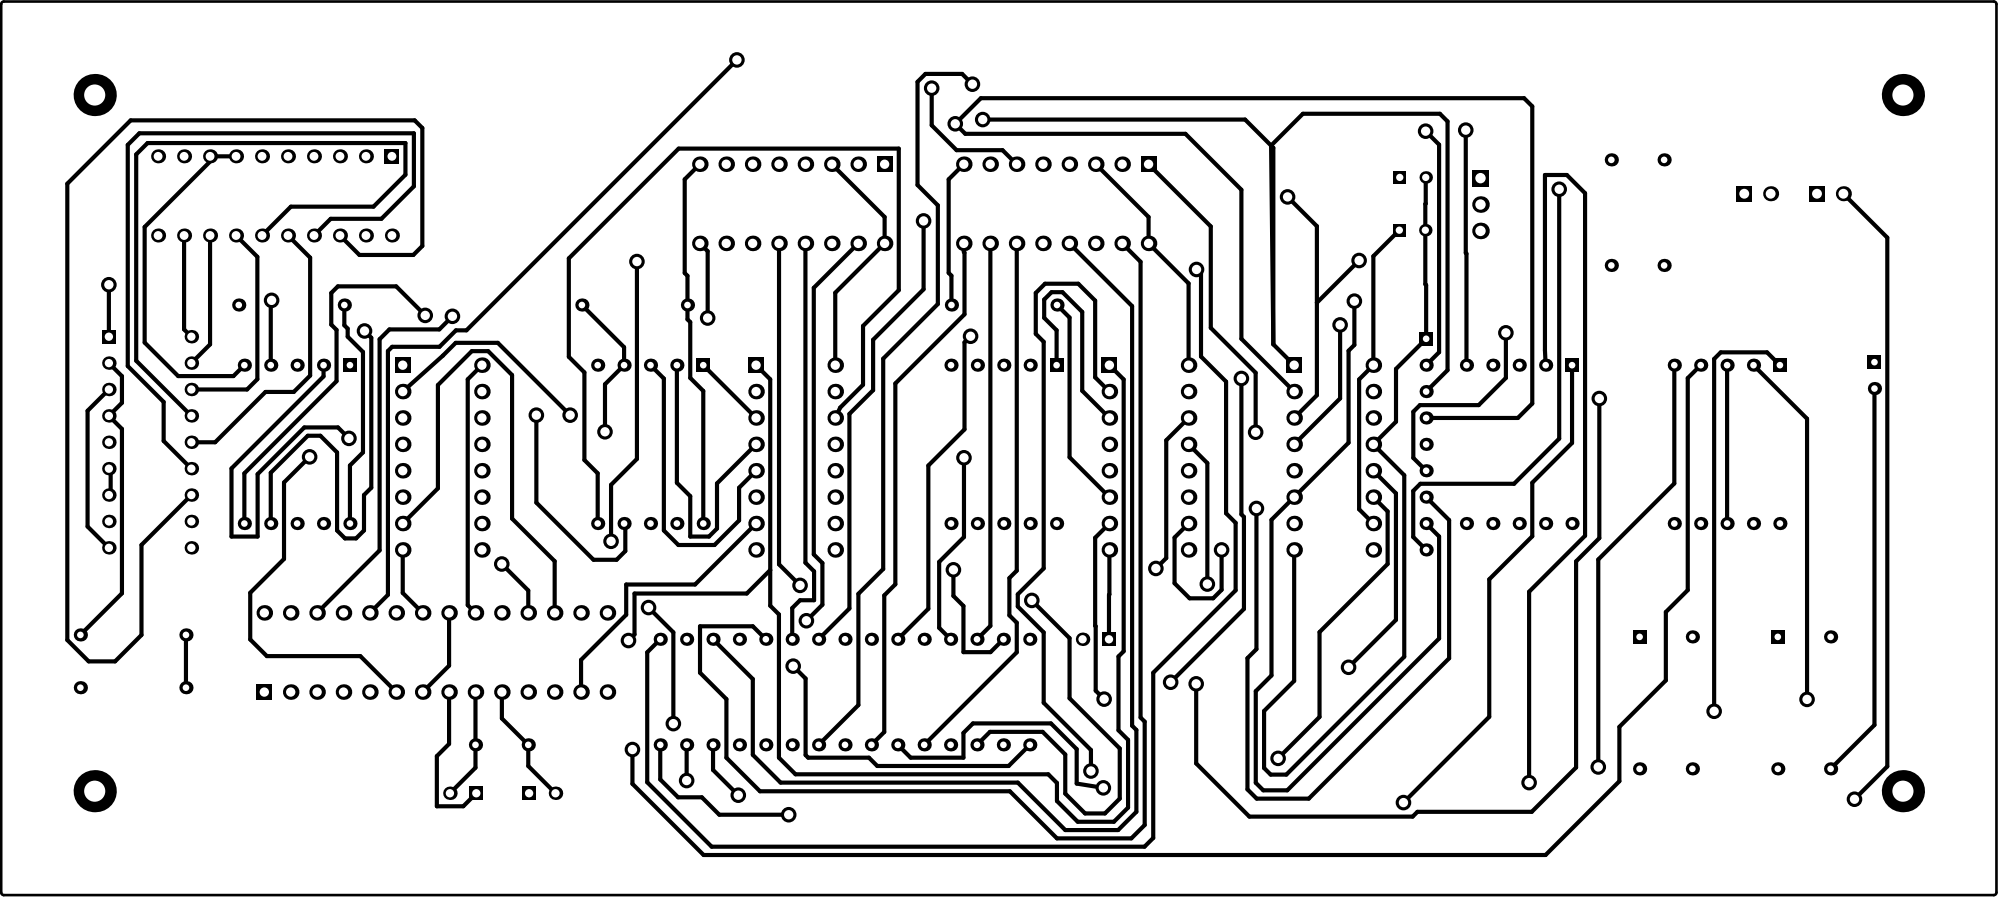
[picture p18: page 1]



CalcWizard v1.0 - EE356 Teaching Aid Project





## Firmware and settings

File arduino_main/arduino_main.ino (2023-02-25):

// ------------------------------------------------------------------------------------------------
/* 
 * EE356: Electronic Product Design
 * Course Project
 * 
 * A portable teaching aid that can be used to teach basic arithmetic
 * operations to primary school children ages 6-8 years old.

 * E/17/146 Jayawickrama J. P. D.
 * E/17/234 Pandukabhaya V. K. M.
 * E/17/371 Warnakulasuriya R.
 */

// ------------------------------------------------------------------------------------------------
// ------------------------------------------------------------------------------------------------

#pragma region "Constants"

// #defines
#define DEBUG true                      // Set to true for debug output, false for no debug output
#define DEBUG_SERIAL if(DEBUG) Serial

// Pin designations
const int Pin_CLK                =  4;  // Synchronous clock signal

// Pins for the block inputs
// TODO: Check whether we can use a common enable line for the three blocks (that would be easier)
const int Pin_Num1_Data          = 11;  // Block 1 PISO(165)reg Qh' pin (Ard 11 -> 165 num1 pin 7)
const int Pin_Op_Data            =  7;  // Operator block PISO(165)reg Qh' pin (Ard 7 -> 165 op pin 7)
const int Pin_Num2_Data          =  9;  // Block 2 PISO(165)reg Qh' pin (Ard 7 -> 165 num2 pin 7)
const int Pin_Block_Shift_Load   = 12;  // Block PISO(165) register SH/LD pin (6): H: shift, L: load
const int Pin_Block_CLK_Inhibit  = 17;  // Block PISO(165) register CLK INH pin (Ard A3 -> Pin 15)

// Array of input data pins
int Pin_Block_Array[3]           = {Pin_Num1_Data, Pin_Op_Data, Pin_Num2_Data};

// Pins for the display unit
const int Pin_Display_Enable     =  6;  // BCD-7S Decoder(47) (Ard D6 -> BI/RBO' pin)                  // unused in prototype/PCB
const int Pin_Display_Data       =  5;  // Display SIPO(595) register SER pin (Ard D5 -> 595 pin 14)
const int Pin_Display_Reg_Enable =  8;  // Display SIPO(595) register RCLK pin (Ard D8 -> 595 pin 12)
const int Pin_Green_LED          = 15;  // Correct answer feedback LED pin (Ard A1 -> Green LED +)
const int Pin_Red_LED            = 16;  // Wrong answer feedback LED pin (Ard A2 -> Red LED +)
const int Pin_BarGraph_PWM       = 10;  // LED bar graph PWM output (Ard D10 -> LM3914 Filter input)

// Analog pins
const int Pin_Battery_Level      = 14;  // Analog input pin for battery level                          // unused in prototype/PCB

//Interrupt pins
const int Pin_Next_Interrupt     =  2;  // Next button pin
const int Pin_Submit_Interrupt   =  3;  // Submit button pin

#pragma endregion

// ------------------------------------------------------------------------------------------------

#pragma region "Constant data"

// Possible number combinations
int ValidNumberList[40] = {  0,  1,  2,  3,  4,  5,  6,  7,  8,  9, 10, 11, 12, 13, 14, 
                            15, 16, 17, 18, 20, 21, 24, 25, 27, 28, 30, 32, 35, 36, 40, 
                            42, 45, 48, 49, 54, 56, 63, 64, 72, 81};

int Serial_Baud_Rate          = 9600;   // Serial baud rate (bps)
long debouncing_time          = 100000; // Debouncing time (in us) for push buttons

#pragma endregion

// ------------------------------------------------------------------------------------------------

#pragma region "Global Variables"

int ByteField[3] = {0, 0, 0};           // Bit field to store block data
                                        // i = 0: Num1 block
                                        // i = 1: Operator block
                                        // i = 2: Num2 block

// User inputs: variables for storage
int num1                         = 0;   // User input operand 1
int op                           = 0;   // User input operator
                                        // 0 - Addition, 1 - Subtraction, 2 - Mulitplication
int num2                         = 0;   // User input operand 2
int mode                         = 0;   // User input mode select

int score                        = 0;   // Score accumulated by user
int number                       = 0;   // Number to be made using num1, num2, and op

// Debouncing
volatile unsigned long last_us   = 0;   // Last timestamp (in us) of a button press

// Flags for program flow
volatile int loop_flag           = 0;   // Break out of blink loop after interrupt
volatile int blocks_flag         = 0;   // Check proper connection of input blocks
                                        // 1 if all three blocks are set; 0 otherwise

// ISR flags
volatile bool InterruptOccurred       = false;
volatile bool NextButtonISROccurred   = false;
volatile bool SubmitButtonISROccurred = false;

#pragma endregion

// ------------------------------------------------------------------------------------------------
// ------------------------------------------------------------------------------------------------

#pragma region "Function prototypes (declarations)"

void NextButtonPress();
void SubmitButtonPress();

bool CheckBlockConectivity();
void ReadFromBlocks();
void SendDigitsToDisplay(int data_pin, int digit_10, int digit_1);
int  ReadBatteryLevel();
void GenerateNumber();
void ModeFunction0();
void ModeFunction1to3();
void BlinkLED(int LED_pin, int On_duration, int Off_duration, int Blink_count);

/*void DisplayTest01();
void DisplayTest02();
void DisplayTest03();*/

#pragma endregion

// ------------------------------------------------------------------------------------------------

#pragma region "Generic functions"
void BlinkLED(int LED_pin, int On_duration, int Off_duration, int Blink_count) {
    for (int p = 1; p <= Blink_count; p++) {
        digitalWrite(LED_pin, HIGH);
        delay(On_duration);
        digitalWrite(LED_pin, LOW);
        delay(Off_duration);
    }
}
#pragma endregion

// ------------------------------------------------------------------------------------------------

#pragma region "Interrupt service routines (ISRs)"

// A wrapper function for push button debouncing 
void Debounce(void (*)());
void Debounce(void (*function)()) {
    if ((long) (micros() - last_us) >= debouncing_time) {
        InterruptOccurred = true;
        //noInterrupts();

        NextButtonISROccurred   = false;
        SubmitButtonISROccurred = false;
        
        (*function)(); // run the function given in argument
        last_us = micros();
        
        delay(500); // Inhibit further bounces for this many ms

        InterruptOccurred = false;
        //interrupts();
    }
}


// ISR for Next button press
// Sets NextButtonISROccurred
void ISRNextButtonPress() {
    if (!InterruptOccurred)
        NextButtonISROccurred   = true;
}


// ISR for Submit button press
// Sets SubmitButtonISROccurred
void ISRSubmitButtonPress() {
    if (!InterruptOccurred)
        SubmitButtonISROccurred = true;
}


// To run when user presses next. TODO: implement the LED bar graph
void NextButtonPress() {
    loop_flag = 0; // Break the loop
    
    DEBUG_SERIAL.println(" ");
    DEBUG_SERIAL.println("Next button interrupt occurred");

    digitalWrite(Pin_Green_LED, LOW);
    digitalWrite(Pin_Red_LED,   LOW);

    if (score == 10) {
        analogWrite(Pin_BarGraph_PWM, 0);
        // TODO: clear bar graph
    }

    // Generate a random number and send it to the display
    GenerateNumber();
}


// To run when user submits an answer. TODO: implement the LED bar graph, fix debounce.
void SubmitButtonPress() {
    blocks_flag = 0; // Break the loop

    DEBUG_SERIAL.println(" ");
    DEBUG_SERIAL.println("Submit button interrupt occurred");

    digitalWrite(Pin_Green_LED, LOW);
    digitalWrite(Pin_Red_LED, LOW);
    ReadFromBlocks();

    if (blocks_flag == 1) { // Check if all three blocks are inserted
        if (mode == 0) {
            ModeFunction0();
        }
        else if (mode > 0 && mode <= 3) {
            ModeFunction1to3();
        }
        // TODO: update the bar graph
        if (score == 10) {
            loop_flag = 1;
            while (loop_flag) {
                BlinkLED(Pin_Green_LED, 250, 250, 1);
                // TODO: Turn on all bar graph LEDs
                // TODO: Turn off all bar graph LEDs
                
                //digitalWrite(Pin_Green_LED, HIGH);
                //delay(250);
                //digitalWrite(Pin_Green_LED, LOW);
                //delay(250);
            }
        }
    }
    else {
        // Error: At least one block is not inserted
        DEBUG_SERIAL.println("At least one block is not inserted");
        BlinkLED(Pin_Red_LED, 500, 500, 1);
        BlinkLED(Pin_Green_LED, 500, 500, 1);
    }

    /*
    for (int p = 0; p <= 255; p++) {
        analogWrite(Pin_BarGraph_PWM, p);
        delayMicroseconds(500000);
        DEBUG_SERIAL.print(p);
        DEBUG_SERIAL.println(micros());
    }
    for (int p = 255; p >= 0; p--) {
        analogWrite(Pin_BarGraph_PWM, p);
        delayMicroseconds(500000);
        DEBUG_SERIAL.print(p);
        DEBUG_SERIAL.println(micros());
    }
    */
}

#pragma endregion

// ------------------------------------------------------------------------------------------------

#pragma region "Main functions"

// Check if all three blocks are connected
bool CheckBlockConectivity() {
    return (((ByteField[0] >> 7) & 0b00000001) && 
            ((ByteField[1] >> 7) & 0b00000001) && 
            ((ByteField[2] >> 7) & 0b00000001));
}


// Reads the parallel-in serial out registers (blocks)
// into bit fields BlockNum1, BlockOp, BlockNum2.
void ReadFromBlocks() {
    DEBUG_SERIAL.println("Read from blocks");

    for (int i = 0; i < 3; i++) {
        // Write a pulse to (SH/LD) pin (load the data to register)
        digitalWrite(Pin_Block_Shift_Load, LOW);  delayMicroseconds(5);
        digitalWrite(Pin_Block_Shift_Load, HIGH); delayMicroseconds(5);

        digitalWrite(Pin_CLK, HIGH); // Rise-edge CLK
        digitalWrite(Pin_Block_CLK_Inhibit, LOW);

        // Read raw data of byte i
        ByteField[i] = ~shiftIn(Pin_Block_Array[i], Pin_CLK, MSBFIRST);
        digitalWrite(Pin_Block_CLK_Inhibit, HIGH);
        digitalWrite(Pin_CLK, LOW); // Fall-edge CLK
    }

    // Interpret the read bit field and obtain the digits and the operator
    // if: check whether the MSB of each block is HIGH (i.e. block inserted)
    if (CheckBlockConectivity()) {
        blocks_flag = 1;
        num1 = ((ByteField[0] >> 4) & 0b00000111)*10 + (ByteField[0] & 0b00001111);
        mode = ( ByteField[1] >> 4) & 0b00000111; // first 4 MSBs except the MSB
        op   =                                          ByteField[1] & 0b00001111;
        num2 = ((ByteField[2] >> 4) & 0b00000111)*10 + (ByteField[2] & 0b00001111);
    }
    else {
        // At least one block is not inserted
        blocks_flag = 0;
        num1 = 0;
        mode = 0;
        op = 0;
        num2 = 0;
    }
}


// Output a two digit number and convert 8-bit serial to parallel
// Send two digits to the display
void SendDigitsToDisplay(int data_pin, int digit_10, int digit_1) {
    int send_data = (digit_10 << 4) + digit_1;
    send_data = ((digit_10 >= 0 && digit_10 <= 9) && (digit_1 >= 0 && digit_1 <= 9)) ? send_data : 0;

    digitalWrite(Pin_Display_Reg_Enable, LOW);
    shiftOut(data_pin, Pin_CLK, MSBFIRST, send_data);
    digitalWrite(Pin_Display_Reg_Enable, HIGH);
}


// Read the battery level from analog pin "Pin_Battery_Level"
// and return a 10-bit integer representing the battery level.
int ReadBatteryLevel() {
    int BatteryLevel10bit = (int) (analogRead(Pin_Battery_Level));
    return BatteryLevel10bit;
}


// Select a random number from the list and display
void GenerateNumber() {
    DEBUG_SERIAL.println("Random number generated");

    // Random number generator
    int rnd_num = random(40);
    number = ValidNumberList[rnd_num];

    // Display the generated number
    int digit_10 = (int) (number / 10);
    int digit_1  = (int) (number % 10);

    digitalWrite(Pin_Display_Enable, LOW);
    SendDigitsToDisplay(Pin_Display_Data, digit_10, digit_1);
    digitalWrite(Pin_Display_Enable, HIGH);

    DEBUG_SERIAL.println(number);
}


// Mode 0 - continuous problems, no score keeping. TODO: Implement bar graph
void ModeFunction0() {
    DEBUG_SERIAL.println("Mode 0");

    int result = 0; // Result of input operation

    // Operation based on input
    if (op == 0) {
        DEBUG_SERIAL.println("Mode 0 addition");
        result = num1 + num2;
    }
    else if (op == 1) {
        DEBUG_SERIAL.println("Mode 0 subtraction");
        result = num1 - num2;
    }
    else if (op == 2) {
        DEBUG_SERIAL.println("Mode 0 multiplication");
        result = num1 * num2;
    }
    // Comparison
    if (result == number) {
        DEBUG_SERIAL.println("Mode 0 correct");
        BlinkLED(Pin_Green_LED, 125, 125, 3);
        digitalWrite(Pin_Green_LED, HIGH);
    }
    else {
        DEBUG_SERIAL.println("Mode 0 incorrect");
        BlinkLED(Pin_Red_LED, 125, 125, 3);
        digitalWrite(Pin_Red_LED, HIGH);
    }
    DEBUG_SERIAL.println(num1);
    DEBUG_SERIAL.println(op);
    DEBUG_SERIAL.println(num2);
    DEBUG_SERIAL.println(result);
    DEBUG_SERIAL.println(number);
}


// Modes 1,2, and 3 - keep score and penalty
void ModeFunction1to3() {
    DEBUG_SERIAL.println("Mode 1to3");

    int penalty = mode - 1; // Score reduction for incorrect answers
    int result = 0;         // Result of input operation
    // Operation based on input
    if (op == 0) {
        DEBUG_SERIAL.println("Mode 1to3 addition");
        result = num1 + num2;
    }
    else if (op == 1) {
        DEBUG_SERIAL.println("Mode 1to3 subtraction");
        result = num1 - num2;
    }
    else if (op == 2) {
        DEBUG_SERIAL.println("Mode 1to3 multiplication");
        result = num1 * num2;
    }
    // Comparison
    if (result == number) {
        DEBUG_SERIAL.println("Mode 1to3 correct");
        score++;
        BlinkLED(Pin_Green_LED, 125, 125, 3);
        digitalWrite(Pin_Green_LED, HIGH);
    }
    else {
        DEBUG_SERIAL.println("Mode 1to3 incorrect");
        score = score - penalty;
        BlinkLED(Pin_Red_LED, 125, 125, 3);
        digitalWrite(Pin_Red_LED, HIGH);
    }
    DEBUG_SERIAL.println(num1);
    DEBUG_SERIAL.println(op);
    DEBUG_SERIAL.println(num2);
    DEBUG_SERIAL.println(result);
    DEBUG_SERIAL.println(number);
}

#pragma endregion

// ------------------------------------------------------------------------------------------------

#pragma region "Setup and main loop"

// Setup
void setup() {
    // I/O pin setup ------------------------------------------------------------------------------

    // Digital outputs
    pinMode(Pin_Block_Shift_Load,   OUTPUT);
    pinMode(Pin_Block_CLK_Inhibit,  OUTPUT); 

    pinMode(Pin_Display_Enable,     OUTPUT); // Display  enable
    pinMode(Pin_Display_Reg_Enable, OUTPUT); // Display reg enable
    pinMode(Pin_Display_Data,       OUTPUT); // Display serial out
    pinMode(Pin_CLK,                OUTPUT); // Synchronous clock
    pinMode(Pin_Green_LED,          OUTPUT);
    pinMode(Pin_Red_LED,            OUTPUT);
    pinMode(Pin_BarGraph_PWM,       OUTPUT);

    // Digital inputs
    pinMode(Pin_Num1_Data,          INPUT);  // Operand 1 serial in
    pinMode(Pin_Num2_Data,          INPUT);  // Operand 2 serial in
    pinMode(Pin_Op_Data,            INPUT);  // Operator  serial in

    // Analog inputs
    pinMode(Pin_Battery_Level,      INPUT);  // Battery voltage

    // Interrupt pins: push buttons
    pinMode(Pin_Next_Interrupt,     INPUT_PULLUP);
    pinMode(Pin_Submit_Interrupt,   INPUT_PULLUP);

    // Set up interrupts
    attachInterrupt(digitalPinToInterrupt(Pin_Next_Interrupt),   ISRNextButtonPress,   RISING);
    attachInterrupt(digitalPinToInterrupt(Pin_Submit_Interrupt), ISRSubmitButtonPress, RISING);

    // --------------------------------------------------------------------------------------------

    // Initial executions -------------------------------------------------------------------------
    
    // Begin serial monitor only if DEBUG flag is set
    DEBUG_SERIAL.begin(Serial_Baud_Rate);

    // Set random seed for the random number generator
    randomSeed(analogRead(Pin_Battery_Level));

    // Starting chime
    BlinkLED(Pin_Green_LED, 125, 125, 1);
    BlinkLED(Pin_Red_LED,   125, 125, 1);

    // Set initial states of the digital pins
    digitalWrite(Pin_Display_Enable, LOW);
    digitalWrite(Pin_Green_LED, LOW);
    digitalWrite(Pin_Red_LED, LOW);

    ReadFromBlocks();
    GenerateNumber();

    // --------------------------------------------------------------------------------------------
}


// Main loop
void loop() {
    // Process interrupt flags
    if (NextButtonISROccurred)
        Debounce(NextButtonPress);
    else if (SubmitButtonISROccurred)
        Debounce(SubmitButtonPress);
}

#pragma endregion

// ------------------------------------------------------------------------------------------------





















// ------------------------------------------------------------------------------------------------

// Test functions

#pragma region "Test functions"

// Test shift registers and seven segment display
// Example code for serial communication for the 7SSDs
/*
void DisplayTest01() {
    SendDigitsToDisplay(Pin_Display_Data, 0, 0);
    digitalWrite(Pin_Display_Enable, HIGH);
    delay(1000);
    for (int i = 0; i <= 9; i++) {
        for (int j = 0; j <= 9; j++) {
            SendDigitsToDisplay(Pin_Display_Data, i, j);
            delay(50);
        }
    }
    digitalWrite(Pin_Display_Enable, LOW);
    delay(1000);
}
*/
// Display input block values on SSD
/*
void DisplayTest02 () {
    
    // TODO: do this reading part when an interrupt occurs
    ReadFromBlocks();

    // Process raw data
    int b1d1 = (ByteField[0] >> 4) & 0b00001111;
    int b1d0 =  ByteField[0]       & 0b00001111;
    int opd1 = (ByteField[1] >> 4) & 0b00001111;
    int opd0 =  ByteField[1]       & 0b00001111;
    int b2d1 = (ByteField[2] >> 4) & 0b00001111;
    int b2d0 =  ByteField[2]       & 0b00001111;

    SendDigitsToDisplay(Pin_Display_Data, b1d1, b1d0);
    digitalWrite(Pin_Display_Enable, HIGH);
    delay(1000);
    SendDigitsToDisplay(Pin_Display_Data, opd1, opd0);
    digitalWrite(Pin_Display_Enable, HIGH);
    delay(1000);
    SendDigitsToDisplay(Pin_Display_Data, b2d1, b2d0);
    digitalWrite(Pin_Display_Enable, HIGH);
    delay(1000);

    digitalWrite(Pin_Display_Enable, LOW);
    delay(1000);
}
*/
/*
// Send two predefined digits to the display
void DisplayTest03() {
    SendDigitsToDisplay(Pin_Display_Data, 3,3);
}
*/

#pragma endregion

// ------------------------------------------------------------------------------------------------

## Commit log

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2022-11-05 Synchronized Arduino codes within simulation and outside
    Redefined global variable names. Have to discuss whether a common clock should be used or not.
2022-11-06 Update proteus_simulation.pdsprj
    Added 4 more switches to each block so that each block represents 8 bits.
2022-11-06 Arduino Firmware revision and synchronization
    Removed unnecessary pin designations. Copied firmware from simulation to .ino file.
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2022-11-22 Pin designation, I/O functions
    - Fix pin designation
    - Move test code to a separate function
    - Add get_data and send_data functions
    - Prototype all except built-in arduino functions
    [arduino_main.ino]
2022-11-22 Fix get_data return value
    [arduino_main.ino]
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2022-11-23 Create Breadboard layout.fzz
    A Fritzing schematic for the breadboard implementation
    [Breadboard layout.fzz]
2022-11-23 Update Breadboard layout.fzz
    [Breadboard layout.fzz]
2022-11-25 Updated .ino, simulation, breadboard layout
    - Wired up the breadboard layout (revision needed)
    - Replaced 74LS164 with 74HC595
    - Updated the code to reflect the hardware changes
    [Breadboard layout.fzz]
2022-11-26 Move notes
    [Breadboard layout.fzz]
2022-11-27 Clarify pin comments add functions
    - Include IC and pin names in commnets
    - Move test code to DiplayTest02()
    - Add GenerateNumber()
    - Add ModeFunction0()
    - Add ModeFunction1to3()
    - Add StartButtonPress()
    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
2022-11-27 Implement interrups and fix common cathode SSD
    [arduino_main.ino]
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2022-11-27 Update arduino_main.ino
    Code corrections and cleaning up
    [arduino_main.ino]
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2022-11-27 Fix redundant result declaration, feedback LED
    [arduino_main.ino]
2022-11-27 Fix garbage values generated number
    [arduino_main.ino]
2022-11-27 Update readme, rename prototype directory
    [prototype_layout.fzz]
2022-12-19 Create digit_block.fzz
    Created a Fritzing file to design the digit/operator/general blocks.
    [digit_block.fzz]
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2022-12-26 Reorganize Fritzing files
    - Move prototype_layour.fzz to /fritzing_diagrams
    - Move digit_block.fzz to /fritzing_diagrams/hardware_implementation
    [digit_block.fzz, prototype_layout.fzz]
2022-12-26 Uploaded the Altium PCB project files
    [PCB1.PcbDoc, PCB_Project.PrjPcb, PcbLib1.PcbLib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]
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2022-12-27 Updated PCB design
    Converted pull down resistors to resistor packs
    [PCB1.PcbDoc, PcbLib1.PcbLib, Schlib1.SchLib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]
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2022-12-27 Change directory name
    [PCB1.PcbDoc, PCB_Project.PrjPcb, PcbLib1.PcbLib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]
2022-12-28 Updated PCB design
    [PCB1.PcbDoc, Sheet1.SchDoc]
2022-12-28 Update PCB design
    [Sheet1.SchDoc]
2022-12-28 Updated PCB design
    Added the voltage regulator circuitry
    [PCB1.PcbDoc, PcbLib1.PcbLib, Schlib1.SchLib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]
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2022-12-29 Update PCB and simulation
    [PCB_Project.PrjPcb, Sheet1.SchDoc]
2022-12-31 Update PCB design
    Added PCB mounting holes
    [PCB1.PcbDoc, PCB_Project.PrjPcb, PcbLib1.PcbLib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]
2022-12-31 Created directory "enclosure"
    Moved in the files related to enclosure design to GitHub
    [Top of the Enclosure v13.dwg, Top of the Enclosure v13.f3z]
2023-01-07 Updated PCB design
    - Added the crystal oscillator
    [PCB1.PcbDoc, PcbLib1.PcbLib, Schlib1.SchLib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]
2023-01-08 Update PCB design
    - Moved the crystal oscillator towards the uC
    - Rerouted
    [PCB1.PcbDoc]
2023-01-08 Generated files for PCB manufacture
    - Gerber
    - BOM
    - Drill
    - Schematics
    [Bill of Materials-PCB_Project.xlsx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]
2023-01-17 Adjust routing rules
    [PCB1.PcbDoc, Sheet1.SchDoc]
2023-02-08 Auto-routed PCB with revised design rules
    [PCB1.PcbDoc]
2023-02-08 Added an RC filter to the bar graph
    [PCB1.PcbDoc, Sheet1.SchDoc]
2023-02-08 Updated PCB generated content
    [Bill of Materials-PCB_Project.xlsx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]
2023-02-11 Placed the RC filter (unrouted)
    [PCB1.PcbDoc, PCB_Project.PrjPcb, Sheet1.SchDoc]
2023-02-16 Update PCB design
    - Re-positioning of PCB mounting holes (+-0.5 mm)
    [PCB1.PcbDoc]
2023-02-16 Updated the PCB design
    - Resized board size to 192x86 mm
    [PCB1.PcbDoc]
2023-02-16 Updated PCB design
    - Solder mask adjustment
    [PCB1.PcbDoc, PCB_Project.PrjPcb]
2023-02-16 Updated PCB design
    - Re-routed with more relaxed routing rules
    [PCB1.PcbDoc, Sheet1.SchDoc]
2023-02-16 added block pcbs?
    [PCB1.PcbDoc, PCB_Blocks.PrjPcb, PcbLib1.PcbLib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]
2023-02-17 Created schematic for input blocks
    - block PCB not updated
    [Bill of Materials-PCB_Project.xlsx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]
2023-02-17 Updated and routed block PCB
    - connections between block are also routed, but unnecessary
    [PCB1.PcbDoc, Sheet1.SchDoc]
2023-02-17 Single side routing
    [PCB1.PcbDoc]
2023-02-17 Restrict routing outside blocks
    [PCB1.PcbDoc, Sheet1.SchDoc]
2023-02-17 fix gnd pin disconnection
    [PCB1.PcbDoc, Sheet1.SchDoc]
2023-02-17 connect enable (h) pin to vcc
    [PCB1.PcbDoc, Sheet1.SchDoc]
2023-02-17 Updated PCB design
    - Updated the PCB label
    [PCB1.PcbDoc]
2023-02-17 Updated PCB design
    - Ungrounded the PCB mounting holes
    - Temporarily removed the pull down resistors of blocks
    [PCB1.PcbDoc, Sheet1.SchDoc]
2023-02-17 Updated PCB design
    - Added a pull-down resistor to the enable pin of each blocks
    [PCB1.PcbDoc, Sheet1.SchDoc]
2023-02-18 Updated PCB design
    - Generated a guide document for laser cutting
    [PCB1.PcbDoc, PcbLib1.PcbLib, Schlib1.SchLib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]
2023-02-18 Synchronization
    - Updated PCB design (routine saving)
    - Synchronized pin designations with code, prototype, PCB
    [PCB1.PcbDoc, Sheet1.SchDoc]
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2023-02-18 Near-finalization
    - Re-routed the PCB
    - Finalized the PCB for blocks
    - etc.
    [Bill of Materials-PCB_Project.xlsx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]
2023-02-19 Updated PCB design
    - Cumulative updates
    [Bill of Materials-PCB_Project.xlsx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]
2023-02-19 Update PCB_Blocks.PcbDoc
    - Increased routing width to 0.8 mm
    [PCB_Blocks.PcbDoc]
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2023-02-22 Rename directory
    [Top of the Enclosure v13.dwg, Top of the Enclosure v13.f3z]
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
